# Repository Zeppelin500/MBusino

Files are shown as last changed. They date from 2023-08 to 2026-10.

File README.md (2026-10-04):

# MBusino
<br/>
### M-Bus --> MQTT-Gateway with shields for ESPs

A **Plug and Play** solution.

M-Bus decoding uses the project's own library [**MBusinoLib**](https://github.com/Zeppelin500/MBusinoLib). Test the library [**via Wokwi.**](https://wokwi.com/projects/402235052803622913)
The serial data link layer communication is handled by [**MBusCom**](https://github.com/Zeppelin500/MBusCom).

Mbusino has a captive and setup portal to configure WiFi, MQTT, M-Bus, and Sensors.

## Code

the project is developed with **Arduino IDE 2**, source code and .bin files will be find at the **src** folder.  

**MBusino** code is for a single M-Bus Slave

**MBusino5S** code is for up to 5 Slaves

## Hardware

### MBusino

The original MBusino decodes M-Bus and can also optional read out different sensors, see below. Network connection only via the build in ESP32 WiFi.
- M-Bus e.g. heatmeter (up to five slaves, use the 5S code)
- OneWire 5x DS18B20, temperature
- I²C BME280, temperatur, r. humidity, air pressure

The MBusino is usable for "only M-Bus" or "only sensor measuring" as well. Beside the USB power supply of The ESP is no other adapter necessary.

Use 2,54mm terminals or JST XH to connect the DS18B20

You will find a 3D-printable PCB case inside the case folder. The edition Z need a different case, usable for both versions. 
The PCB is designed with fritzing.

M-Bus is provided by a piggyback M-Bus master.
There are two MBusino versions available for two different M-Bus masters.

The "old" version for a chinese M-Bus Master. 
https://a.aliexpress.com/_EyQhgIZ --> the Master **NOT the Slave!** 
Supported ESP-Boards: ESP8266 D1 mini, or D1 mini Pro(4M) with extern antenna for better Wifi range and the ESP32 S2 mini

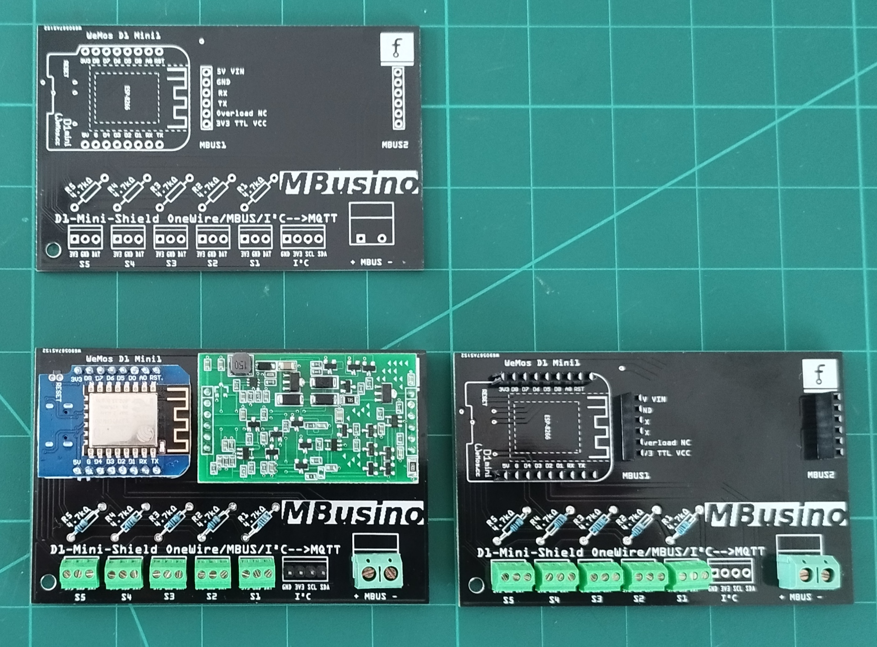
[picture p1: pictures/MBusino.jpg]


The new "**edition Z**" version for a german M-Bus master from Zihatec. Many thanks to HWHardsoft for making the board available especially for us.
https://www.hwhardsoft.de/2024/10/08/m-bus-master-breakout
Work only with the ESP S2 mini.

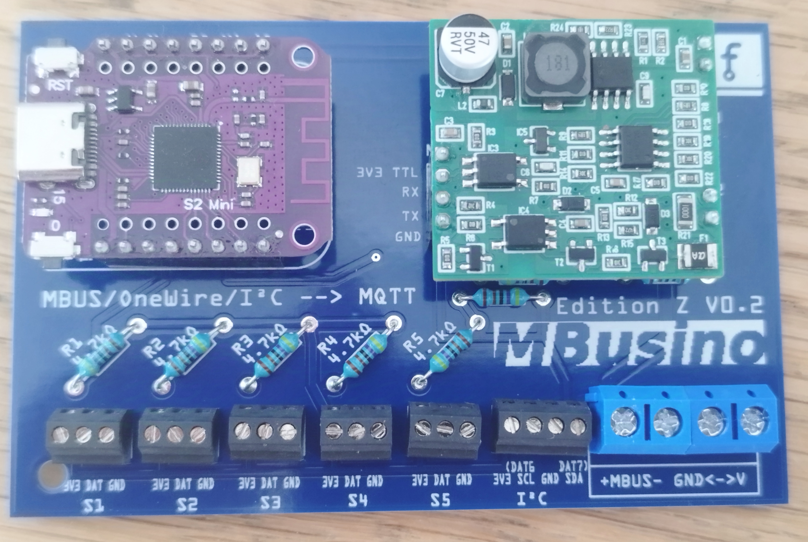
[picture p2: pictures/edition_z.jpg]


### MBusino Nano

A pure M-Bus --> MQTT gateway without extra sensor measuring but with Wifi **and** Ethernet connectivity.
ESP32 C3 Supermini with W5500 Lite Ethernet Modul and Zihatec M-Bus Modul.

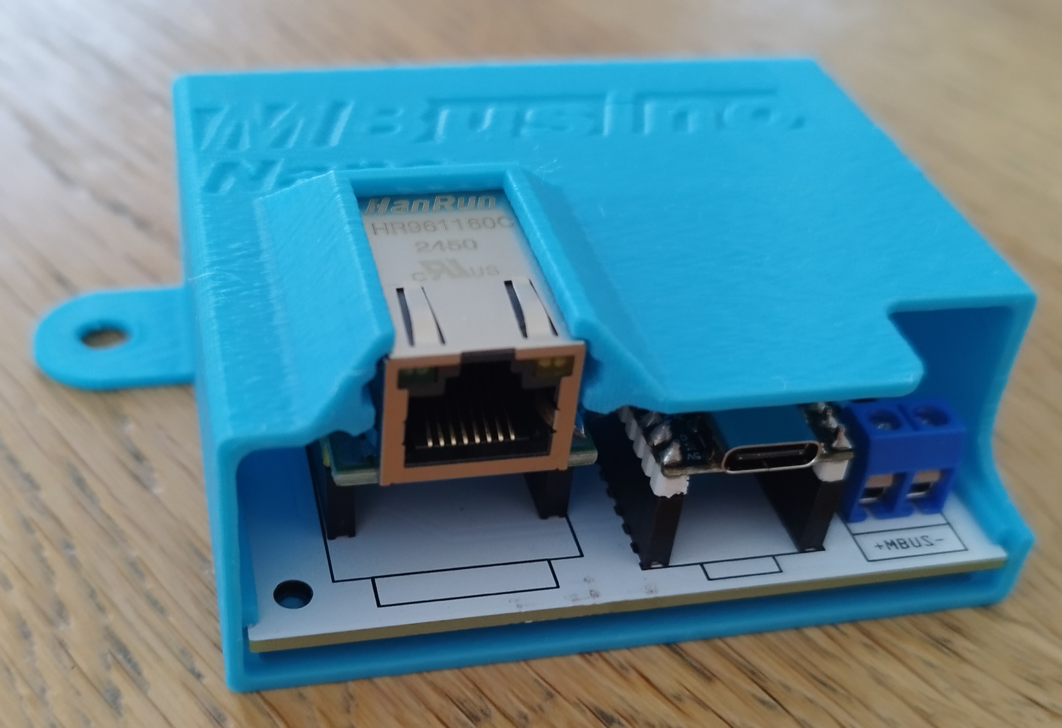
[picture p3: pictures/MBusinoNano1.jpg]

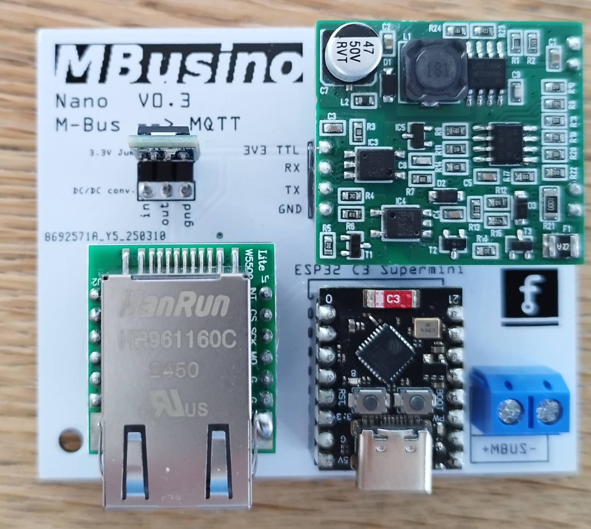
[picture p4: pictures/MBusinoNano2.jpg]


To save money, I place omnibus orders for all parts beside the M-Bus Master.

## Access Point to configure,  MBusino Setup Portal

* SSID **MBusino Setup Portal** IP(normally not needed): 192.168.4.1
* If Mbusino do not find a known network, he start an AP for 5 minutes. After this period, he will restart and search again.
* In known networks, you will find the IP of the portal under **MBusino** in your router.

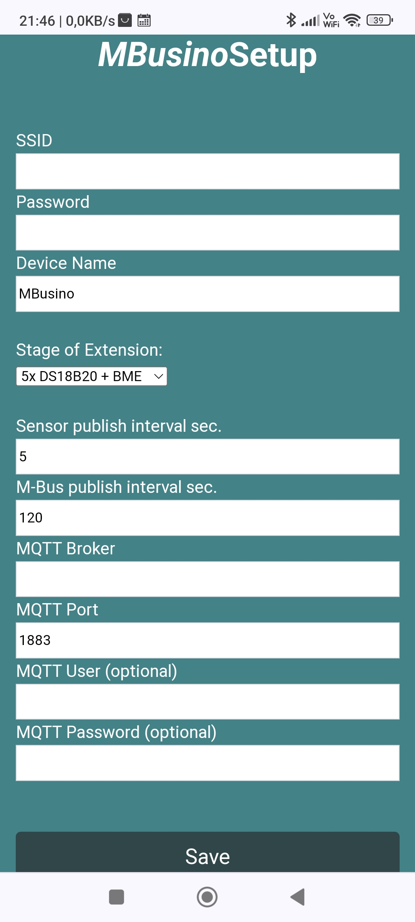
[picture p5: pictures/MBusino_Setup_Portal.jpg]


## MQTT Output
Use MQTT Explorer (PC) or [**MQTT Browser**](https://github.com/ZeppelinsBot/MQTTBrowser) (Android) to see the MQTT Output.

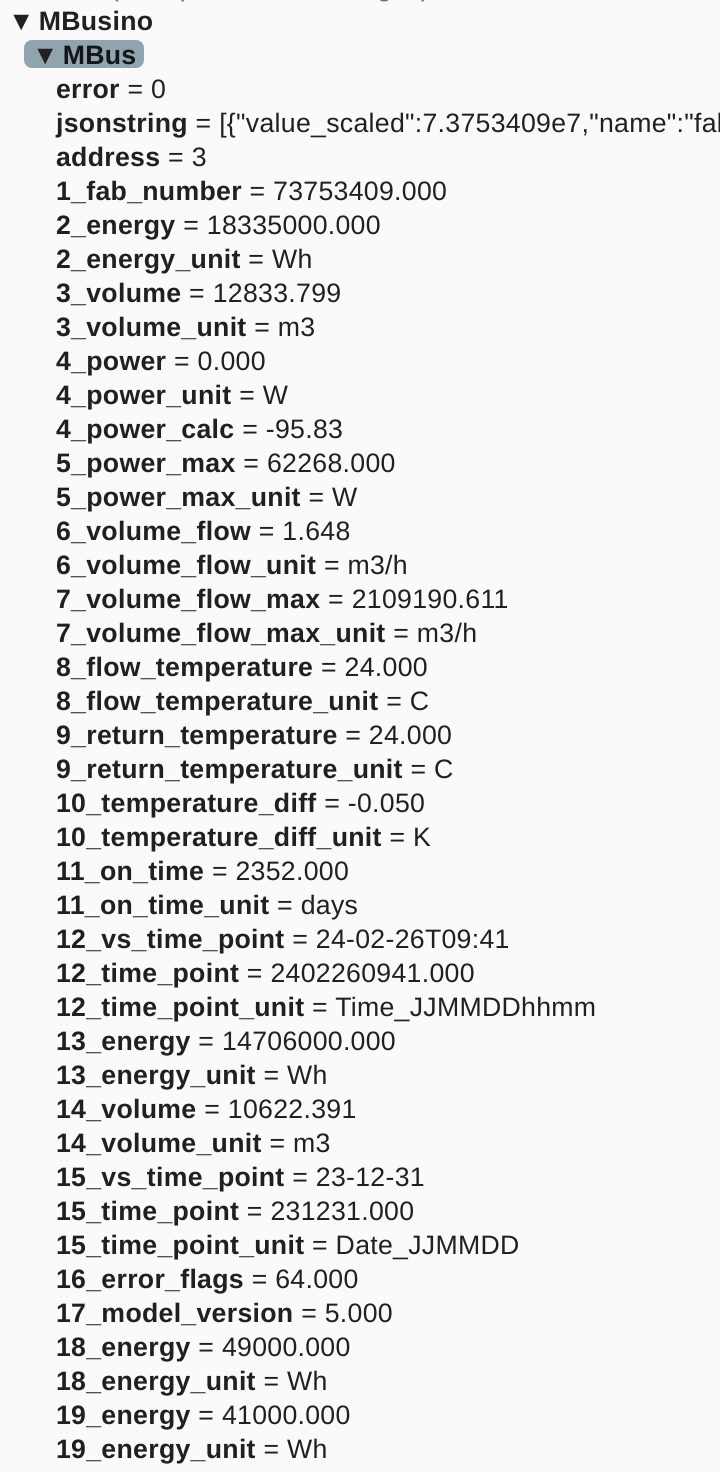
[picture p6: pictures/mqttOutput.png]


## Home-Assistant

If you use Home Assistant, MBusino supports autodiscover. You need only the MQTT integration and MBusino will be find as device with all records.
Every 256th record message is a autodiscover message. 
If you use not Home Assistant, no matter. All records will be send as MQTT message.

## M-Bus Polling (optional)

Normaly M-Bus request is set with an interval at the GUI. But in special cases you can set the interval to a long period to save slave battery life and poll the M-Bus records by a MQTT request as often as you want between. E.g. M-Bus Interval 2.592.000 sec. (30 days) and poll high frequently between in interesting phases.

### MBusino
* MQTT Topic: MBusino/mbusPolling
* MQTT Payload: no matter

### MBusino5S
* MQTT Topic: MBusino/mbusPolling
* MQTT Payload: M-Bus Address in decimal (you can also request addresses witch are not stored in the GUI)

## calibration capabilities 

Most DS18B20 are faked and out of specifications.
You can calibrate the sensors by sending a MQTT message to MBusino.
Subscribe at topic MBusino/cal/# for calibration replies. 

### 1. Set the average of all DS sensors
* MQTT Topic: MBusino/calibrateAverage
* MQTT Payload: no matter

Make the average of the connected sensors and add an offset to every sensor. After the calibration, all sensors will show the same value.
You have to bring all connected sensors to the same environment, wait a little bit and send the calibration message.

### 2. Calibrate to a connected Bosch BME280 Sensor
* MQTT Topic: MBusino/calibrateBME
* MQTT Payload: no matter

Make an offset for every DS sensor based at the meassured value of the BME sensor. After the calibration, all sensors will show the same value.
You have to bring all connected sensors to the same environment, wait a little bit and send the calibration message.

### 3. Calibration by hand
* MQTT Topic: MBusino/calibrateSensor
* MQTT Payload: Number of the Sensor to calibrate (only the number). e.g.S3 = 3
* MQTT Topic: MBusino/calibrateValue
* MQTT Payload: a float number e.g. -0.15

Manipulate the offset of a single sensor by sending sensor numbers and values. The transmitted value will be added to the current offset. First chose the sensor, then send the value. If a sensor is chosed, multiple manipulations of the same sensor are possible.

### 4. Set all offsets to zero
* MQTT Topic: MBusino/calibrateSet0
* MQTT Payload: no matter

Self explanatory.

## known issues / limitations
- Flashing over USB is only possible, if the M-Bus master is not connected (only D1 mini). OTA update work fine.

- Do not use 2 Boards simultaneously without changing thr Name or it cause in network problems, both boards becomes unreachable. 

- M-Bus should work with most M-Bus devices. If you have M-Bus issues, let me know.

- ~~No support of multi telegram messages. Only the first telegram will be decoded~~ done!

- ~~passwords are limited to 29 characters~~ done! now 64 characters 

- If no broker is connected. M-Bus communication is disabled. So, you can't also not change M-Bus addresses from the access point connection.
  
- Some power delivery / quick charge power supplies switch off afer a certain time, because the MBusino requires too little power. Use old addapters without "intelligence". 1A is more then enough.

## Credits
* AllWize for the MbusPayload library -- the first code base of the MBusinoLib to decode M-Bus
* HWHardsoft and TrystanLea for the M-Bus communication

## Current topics

https://github.com/Zeppelin500/MBusino/discussions

## Tutorial

https://github.com/Zeppelin500/MBusino/tree/main/tutorial

## Licence
****************************************************
This program is free software: you can redistribute it and/or modify it under the terms of the GNU General Public License as published by
the Free Software Foundation, either version 3 of the License, or (at your option) any later version. This program is distributed in the hope that it will be useful,
but WITHOUT ANY WARRANTY; without even the implied warranty of MERCHANTABILITY or FITNESS FOR A PARTICULAR PURPOSE.  See the GNU General Public License for more details.
You should have received a copy of the GNU General Public License along with this program.  If not, see <http://www.gnu.org/licenses/>.
****************************************************
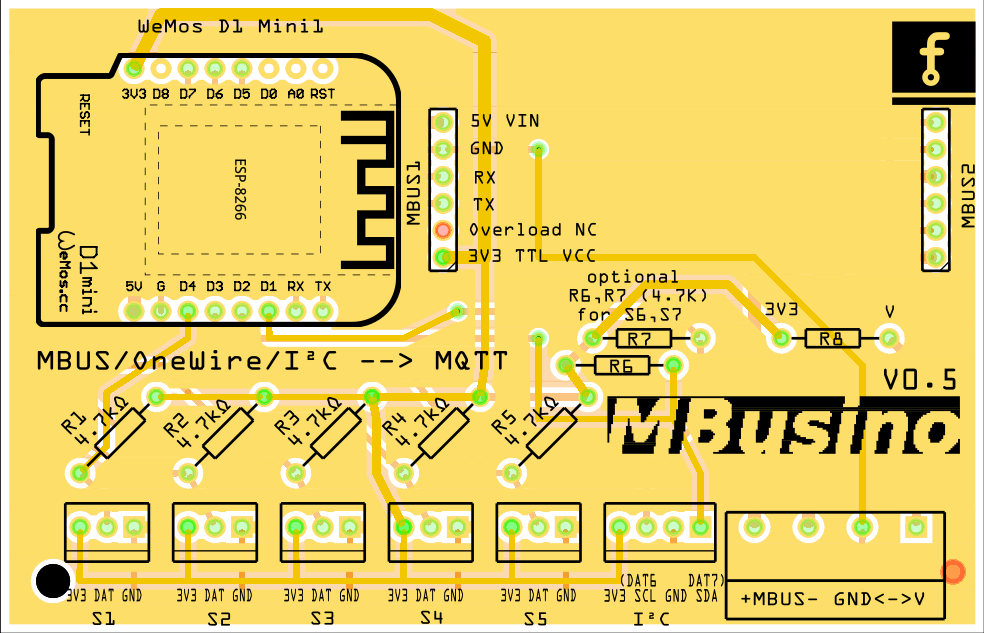
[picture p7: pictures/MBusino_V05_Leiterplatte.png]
PCB

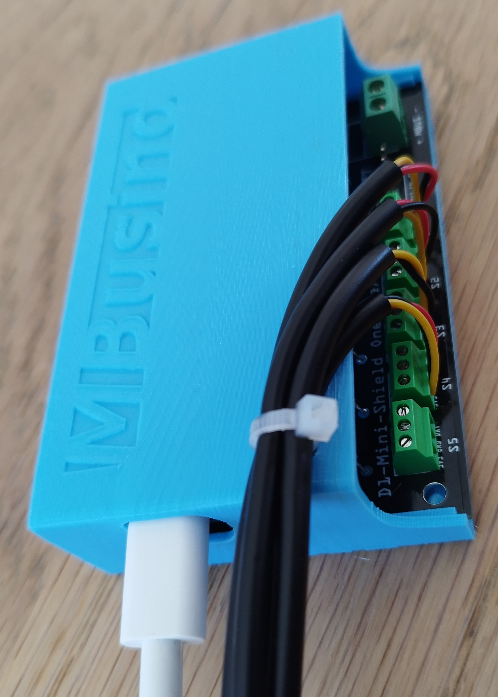
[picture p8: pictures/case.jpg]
Bild


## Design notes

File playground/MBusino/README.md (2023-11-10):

# MBusino
ESP8266 D1 Mini Shield for meassuring and sending some values with MQTT

- M-Bus e.g. heatmeter 
- OneWire 5x z.B. DS18B20, temperature
- I²C z.B. BME280, temperatur, r. humidity, air pressure

* the "old Sensostar only" code is archived.

## Hardware
The PCB is designed with fritzing.
M-Bus is provided by a piggyback M-Bus master.
https://de.aliexpress.com/item/33008746192.html --> the Master!

Beside the USB power supply of D1 Mini is no other adapter necessary.

The Board is usable for only M-Bus (see MBusino_naked code) or only sensor meassuring as well.  

you can use 2,54mm terminals or JST XH to connect the DS18B20

You will find a 3D-printable PCB case inside the case folder.  

To save mony, I place omnibus orders for all parts.

## calibration capabilitys. 

Most DS18B20 are faked and out of specifications.
You can calibrate the sensors by sending a MQTT message to MBusino.

### 1. Set the average of all DS sensors
* MQTT Topic: CMBusino/calibrateAverage
* MQTT Payload: no matter

Make the average of the connected sensors and add an offset to every sensor. After the calibration, all sensors will show the same value.
You have to bring all connected sensors to the same environment, wait a little bit and send the calibration message.

### 2. Calibrate to a connected Bosch BME280 Sensor
* MQTT Topic: CMBusino/calibrateBME
* MQTT Payload: no matter

Make an offset for every DS sensor based at the meassured value of the BME sensor. After the calibration, all sensors will show the same value.
You have to bring all connected sensors to the same environment, wait a little bit and send the calibration message.

### 3. Calibration by hand
* MQTT Topic: CMBusino/calibrateSensor
* MQTT Payload: Number of the Sensor to calibrate (only the number). e.g.S3 = 3
* MQTT Topic: CMBusino/calibrateValue
* MQTT Payload: a float number e.g. -0.15

Manipulate the offset of a single sensor by sending Sensor numbers and values. The transmitted value will be added to the current offset. First chose the sensor, then send the value. If a sensor is chosed, you can manipulate multiple times the same sensor.

### 4. Set all offsets to 0
* MQTT Topic: CMBusino/calibrateSet0
* MQTT Payload: no matter

Self explanatory.

## known issues
- Flashing over USB is only possible if the M-Bus master is not connected. OTA update work fine.

- Do not use 2 Boards without changing the name. #define MBUSINO_NAME "MBusino"

- M-Bus is only tested with a "Engelmann Sensostar U" at the moment, but should work with other M-Bus divices. If you have M-Bus issues, let me know.

- Code will only work with the modified MBUSPayload library. 

https://github.com/Zeppelin500/mbus-payload

## Credits
* AllWize for the library to decode M-Bus
* HWHardsoft for the M-Bus communication

## current topics

https://github.com/Zeppelin500/MBusino/discussions

## Lizenz
****************************************************
This program is free software: you can redistribute it and/or modify it under the terms of the GNU General Public License as published by
the Free Software Foundation, either version 3 of the License, or (at your option) any later version. This program is distributed in the hope that it will be useful,
but WITHOUT ANY WARRANTY; without even the implied warranty of MERCHANTABILITY or FITNESS FOR A PARTICULAR PURPOSE.  See the GNU General Public License for more details.
You should have received a copy of the GNU General Public License along with this program.  If not, see <http://www.gnu.org/licenses/>.
****************************************************
PCB
Bild
Bild

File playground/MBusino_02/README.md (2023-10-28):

# MBusino
Ein ESP8266 D1 Mini Shield zur Aufnahme verschiedener Messwerte und deren Versand per MQTT

* Code funktioniert nur mit der veränderten MBUSPayload Libary. 

* Jetzt sollten verschiedene M-Bus Slaves ausgelesen werden können. 

https://github.com/Zeppelin500/mbus-payload

## Danke  

* an AllWize für die Libary zum dekodieren und
* an HWHardsoft für die M-Bus Kommunikation

## Lizenz GPL3
****************************************************
This program is free software: you can redistribute it and/or modify it under the terms of the GNU General Public License as published by
the Free Software Foundation, either version 3 of the License, or (at your option) any later version. This program is distributed in the hope that it will be useful,
but WITHOUT ANY WARRANTY; without even the implied warranty of MERCHANTABILITY or FITNESS FOR A PARTICULAR PURPOSE.  See the GNU General Public License for more details.
You should have received a copy of the GNU General Public License along with this program.  If not, see <http://www.gnu.org/licenses/>.
****************************************************

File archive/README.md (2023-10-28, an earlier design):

# MBusino
Ein ESP8266 D1 Mini Shield zur Aufnahme verschiedener Messwerte und deren Versand per MQTT

- M-Bus z.B. Wärmemengenzähler 
- OneWire 5x z.B. DS18B20, Temperatur
- I²C z.B. BME280, Temperatur, rel. Luftfeuchte, Luftdruck

## Hardware
Das Shield ist ein mit Fritzing konstruiertes Board.
Der M-Bus wird über einen aufsteckbaren M-Bus Master bereitgestellt.
https://de.aliexpress.com/item/33008746192.html --> der Master!

Ausser der USB Spannungsversorgung des D1 Mini ist kein weiteres Netzteil nötig.

## known issues
- Flashen über USB ist nur möglich, wenn der MBus Master nicht aufgesteckt ist. OTA Update geht aber.

- Das Projekt befindet sich im Aufbau. Der Code ist funktionsfähig. M-BUS ist bis jetzt nur mit dem Sensostar U implementiert.

- ~~Beim aktuellen Prototypen ist die Beschriftung von 3V3 und DAT bei den OneWire Sensoren vertauscht (S1-S5).~~ [bei V0.3 behoben]

## Danke
Der M-Bus Teil und die Headerdateien sind ein Extrakt aus https://github.com/NerdyProjects/HousebusNode_Heatpump
Danke an User NerdyProjects 

## Aktuelles
Hier oben unter Discussion sind die aktuellen Entwicklungsideen zu finden. Beteiligung ist gerne gesehen.
https://github.com/Zeppelin500/MBusino/discussions

* neueste Entwicklung: **MBusino_naked** https://github.com/Zeppelin500/MBusino/tree/main/SRC/MBusino_naked

## Lizenz
****************************************************
This program is free software: you can redistribute it and/or modify it under the terms of the GNU General Public License as published by
the Free Software Foundation, either version 3 of the License, or (at your option) any later version. This program is distributed in the hope that it will be useful,
but WITHOUT ANY WARRANTY; without even the implied warranty of MERCHANTABILITY or FITNESS FOR A PARTICULAR PURPOSE.  See the GNU General Public License for more details.
You should have received a copy of the GNU General Public License along with this program.  If not, see <http://www.gnu.org/licenses/>.
****************************************************
PCB
Bild
Bild

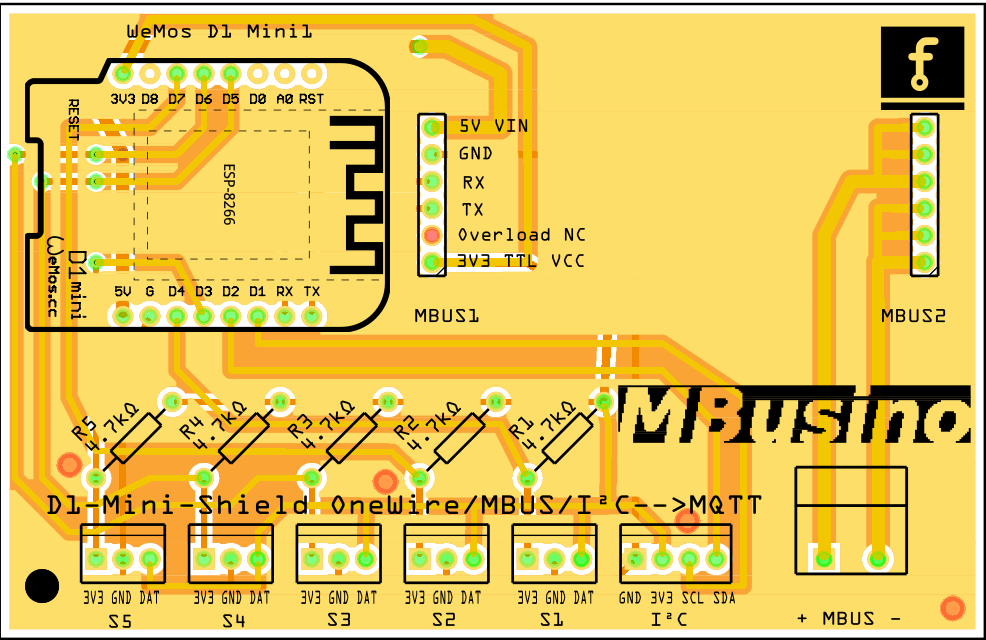
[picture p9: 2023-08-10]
pictures/MBusino.png

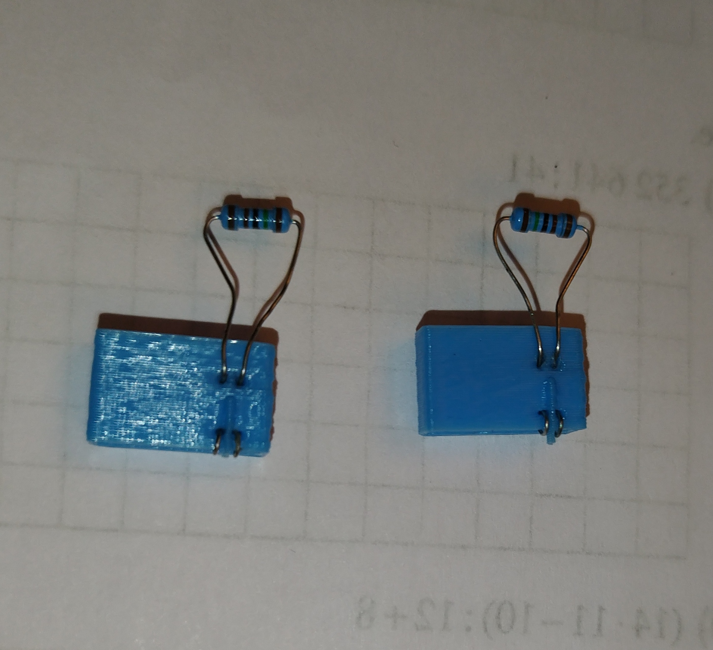
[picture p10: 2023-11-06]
sensostar_dongle/picture3.jpg

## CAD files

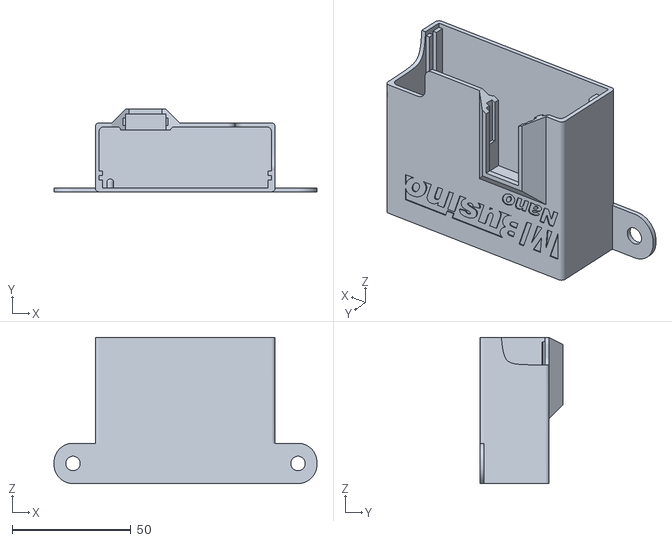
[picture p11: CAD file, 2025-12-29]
case/MbusinoNano v13.stl
110.8 x 34.8 x 61.6

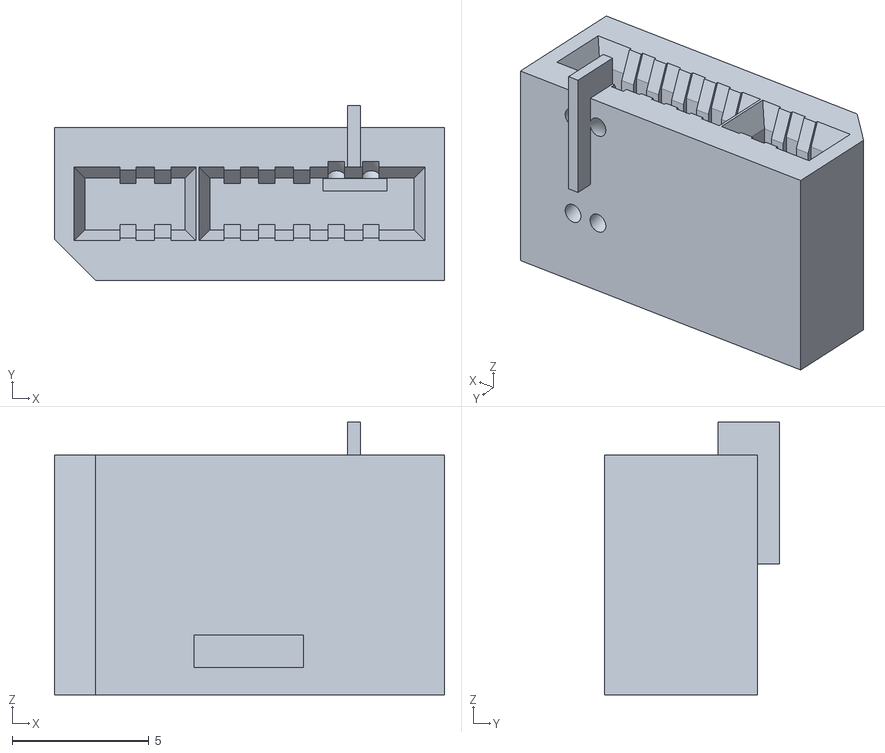
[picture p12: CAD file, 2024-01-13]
sensostar_dongle/stecker v18.stl
14.3 x 6.40 x 9.98

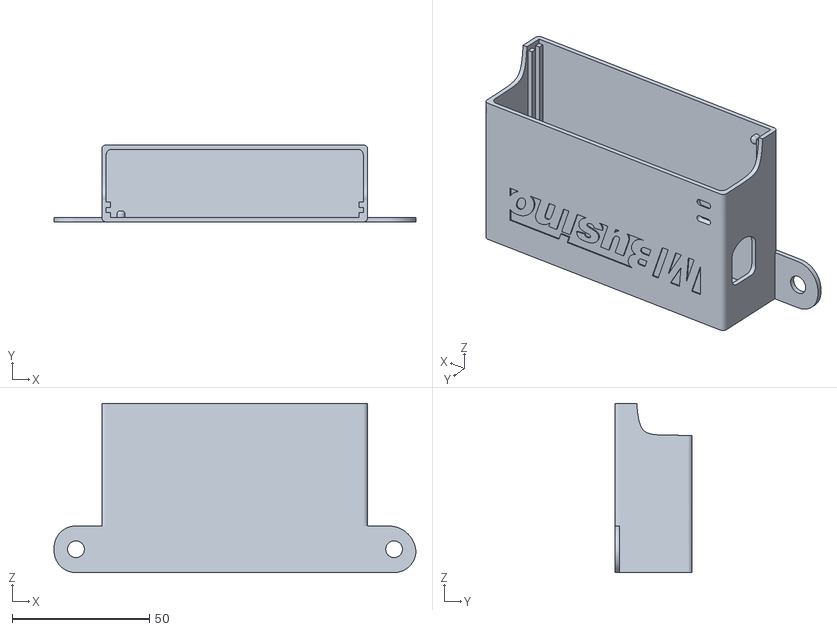
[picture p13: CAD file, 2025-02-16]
case/MbusinoZ v7.stl
131.8 x 28.1 x 61.6

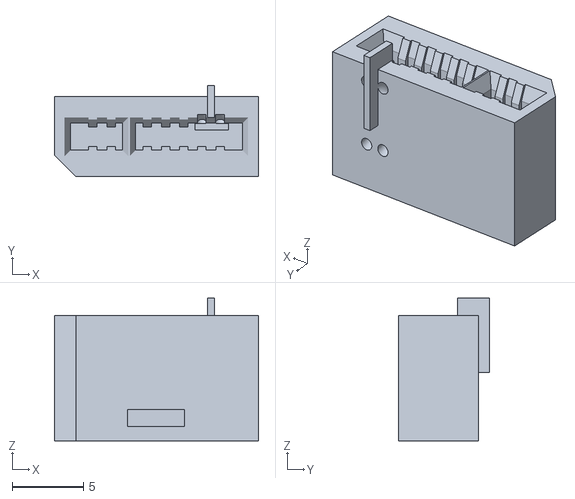
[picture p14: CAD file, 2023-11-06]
sensostar_dongle/sensostar_dongle.stl
14.3 x 6.40 x 9.98

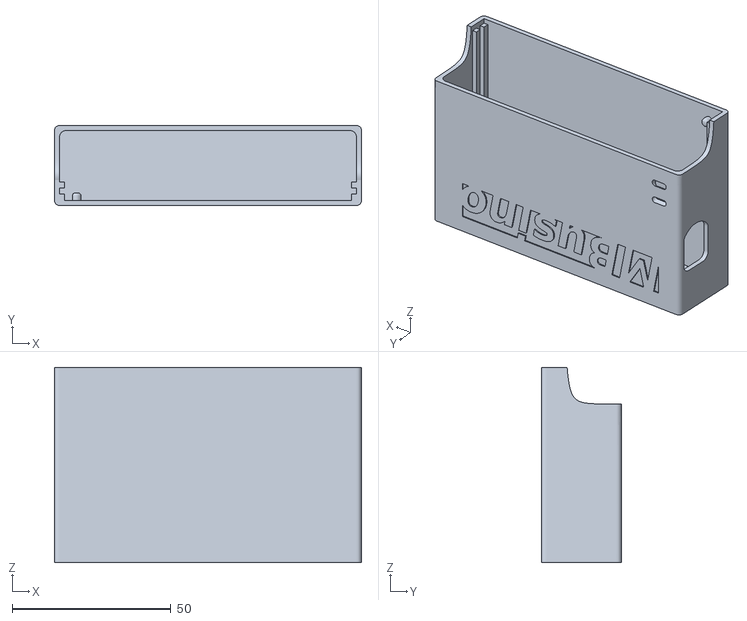
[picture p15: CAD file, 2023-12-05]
case/Mbusino v05.stl
96.8 x 25.2 x 61.6

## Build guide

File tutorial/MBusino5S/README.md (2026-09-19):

# MBusino5S Tutorial

MBusino5S work on **ESP8266 D1 Mini** or **ESP32 S2 Mini**. For both boards are .bin files provided.

https://github.com/Zeppelin500/MBusino/blob/main/src/MBusino5S/build

The Pinout configuration of the ESP32 S2 mini is exactly the same like D1 mini. Equip only the two outside pin headers. 

**Do all steps of the MBusino tutorial (with the MBusino 5S files) and additional the following steps.**
**!Flashing of ESP32 S2 mini is different to the ESP8266 D1 mini, use this [tutorial](https://github.com/Zeppelin500/MBusino/blob/main/tutorial/Flashing_ESP32S2_Mini/README.md)**

## configure MBusino5S

* Number of connected M-Bus Slaves. The Master can handle a maximum of 5 Slaves.
* If you use only 1 slave, set Address 1 to 254. 254 stands for Broadcast and the real address of the slave does no matter.
* If you use more then one slave, you have to set the primary address of the slaves. Possible addresses are 0-250. The connected slaves addresses has to be different! 
* Note, that the M-Bus interval is the time between the M-Bus requests. So if you use 3 slaves and set the interval to 10 seconds. Every single master will answer in a 30 second interval. Minimum is 4 or 5 seconds before the bus were stumbling.
* In delivery condition, the address is 0.

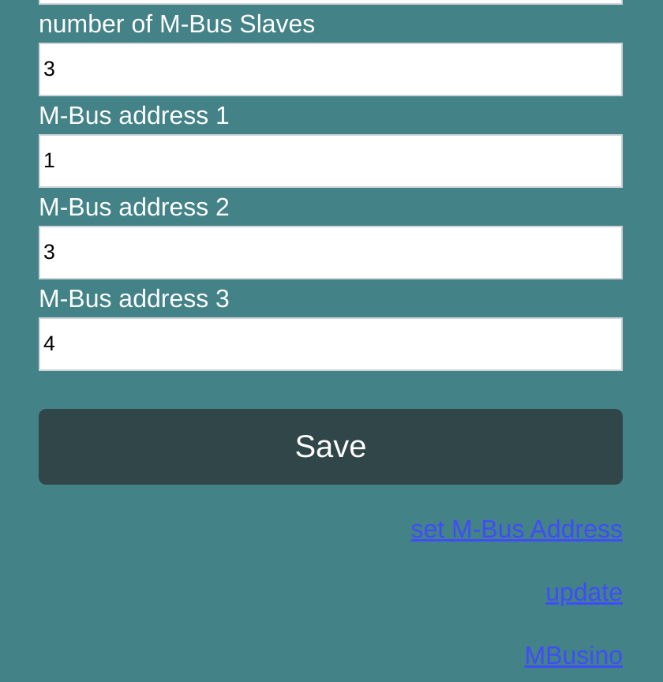
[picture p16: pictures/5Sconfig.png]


## Change the primary addresses of your slaves

* go to **[MBusino_IP]/setaddress**
* only one slave can be connected during setting addresses!
* Choose an address at the drop down and save. 
* the slave should now have the new address 

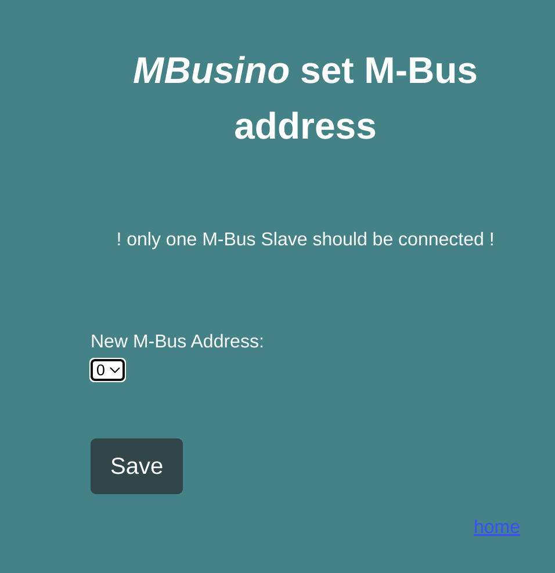
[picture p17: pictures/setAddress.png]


## Output

The MQTT topic output of the MBusino5S is different to the MBusino!
MBus Address is now part of the MQTT topic. So you have to change your Home Assistant config.

MBusino MBus topic:
**MBusino/MBus/6_volume_flow**

MBusino5S MBus topic:
**MBusino/MBus/SlaveAddress3/6_volume_flow**

### Autodiscover

from version 0.9.1, MBusino5S supports Home Assistant autodiscover. You need only the MQTT integration and MBusino will be find as device with all records.
The third record message is a autodiscover message and every 256th recurring.

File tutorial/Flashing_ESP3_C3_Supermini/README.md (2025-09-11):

# Flashing ESP32 C3 supermini for MBusino Nano

For the ESP32 C3 are 3 different .bin files created.

**MBusinoNano**

* MBusinoNano.ino.bootloader.bin
* MBusinoNano.ino.partitions.bin
* MBusinoNano.ino.bin 

https://github.com/Zeppelin500/MBusino/tree/main/src/MBusinoNano/build/esp32.esp32.makergo_c3_supermini

**MBusinoNano5S**

* MBusinoNano5S.ino.bootloader.bin
* MBusinoNano5S.ino.partitions.bin
* MBusinoNano5S.ino.bin 

https://github.com/Zeppelin500/MBusino/tree/main/src/MBusinoNano5S/build/esp32.esp32.makergo_c3_supermini

### Use for Flashing https://adafruit.github.io/Adafruit_WebSerial_ESPTool/

* connect the S2 Mini with USB
* press and hold the boot button, press the reset button, release the boot botton. 
* press **Connect** and choose the USP Port
* if connected click **Erase** and wait for finish
* may you have to connect again
* if connected, load all 3 .bin files as follows with the offset

**MBusino**

* Offset 0x 0000    MBusinoNano.ino.bootloader.bin
* Offset 0x 8000    MBusinoNano.ino.partitions.bin
* Offset 0x 10000    MBusinoNano.ino.bin 

**MBusinoNano5S**

* Offset 0x 0000    MBusinoNano5S.ino.bootloader.bin
* Offset 0x 8000    MBusinNano5S.ino.partitions.bin
* Offset 0x 10000    MBusinoNano5S.ino.bin 

--> done

**The offset of the bootloader in the screenshots are wrong. Use The values above.** 

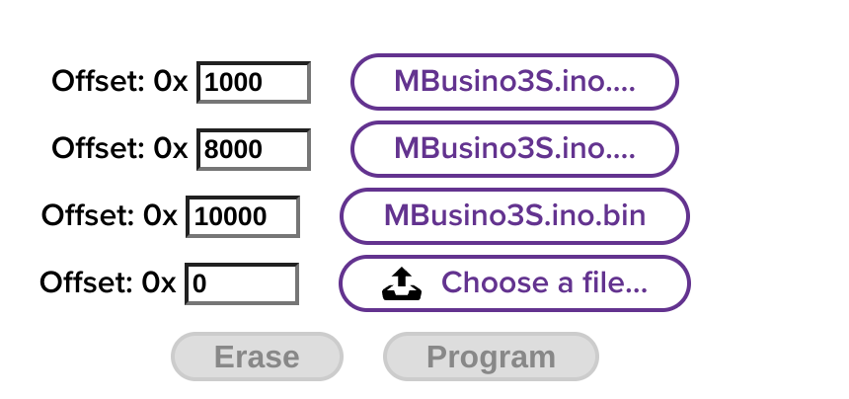
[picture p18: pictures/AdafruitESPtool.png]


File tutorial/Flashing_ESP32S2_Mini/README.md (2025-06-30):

# Flashing ESP32 S2 Mini

For the ESP32 S2 are 3 different .bin files created.

**MBusino**

* MBusino.ino.bootloader.bin
* MBusino.ino.partitions.bin
* MBusino.ino.bin 

https://github.com/Zeppelin500/MBusino/tree/main/src/MBusino/build/esp32.esp32.lolin_s2_mini

**MBusino5S**

* MBusino5S.ino.bootloader.bin
* MBusino5S.ino.partitions.bin
* MBusino5S.ino.bin 

https://github.com/Zeppelin500/MBusino/tree/main/src/MBusino5S/build/esp32.esp32.lolin_s2_mini

### Use for Flashing https://adafruit.github.io/Adafruit_WebSerial_ESPTool/

* connect the S2 Mini with USB
* press and hold the boot button, press the reset button, release the boot botton. 
* press **Connect** and choose the USP Port
* if connected click **Erase** and wait for finish
* may you have to connect again
* if connected, load all 3 .bin files as follows with the offset

**MBusino**

* Offset 0x 1000    MBusino.ino.bootloader.bin
* Offset 0x 8000    MBusino.ino.partitions.bin
* Offset 0x 10000    MBusino.ino.bin 

**MBusino5S**

* Offset 0x 1000    MBusino5S.ino.bootloader.bin
* Offset 0x 8000    MBusino5S.ino.partitions.bin
* Offset 0x 10000    MBusino5S.ino.bin 

--> done



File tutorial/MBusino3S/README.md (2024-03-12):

# MBusino3S Tutorial, 3S for three Slaves

MBusino3S work on **ESP8266 D1 Mini** or **ESP32 S2 Mini**. For both boards are .bin files provided.

https://github.com/Zeppelin500/MBusino/blob/main/src/MBusino3S/build

The Pinout configuration of the ESP32 S2 mini is exactly the same like D1 mini. Equip only the two outside pin headers. 

**Do all steps of the MBusino tutorial (with the MBusino 3S files) and additional the following steps.**
**!Flashing of ESP32 S2 mini is different to the ESP8266 D1 mini, use this [tutorial](https://github.com/Zeppelin500/MBusino/blob/main/tutorial/Flashing_ESP32S2_Mini/README.md)**

## configure MBusino3S

* Number of connected M-Bus Slaves. The Master can handle a maximum of 3 Slaves.
* If you use only 1 slave, set Address 1 to 254. 254 stands for Broadcast and the real address of the slave does no matter.
* If you use more then one slave, you have to set the primary address of the slaves. Possible addresses are 0-250. The connected slaves addresses has to be different! 
* Note, that the M-Bus interval is the time between the M-Bus requests. So if you use 3 slaves and set the interval to 10 seconds. Every single master will answer in a 30 second interval. Minimum is 4 or 5 seconds before the bus were stumbling.
* In delivery condition, the address is 0.



## Change the primary addresses of your slaves

* go to **[MBusino_IP]/setaddress**
* only one slave can be connected during setting addresses!
* Choose an address at the drop down and save. 
* the slave should now have the new address 



## Output

The MQTT topic output of the MBusino3S is different to the MBusino!
MBus Address is now part of the MQTT topic. So you have to change your Home Assistant config.

MBusino MBus topic:
**MBusino/MBus/6_volume_flow**

MBusino3S MBus topic::
**MBusino/MBus/SlaveAddress3/6_volume_flow**

### Autodiscover

from version 0.9.1, MBusino3S supports Home Assistant autodiscover. You need only the MQTT integration and MBusino will be find as device with all records.
The third record message is a autodiscover message and every 256th recurring.

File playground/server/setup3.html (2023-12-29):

# MBusinoSetup

SSID

Password

Device Name

Stage of Extension:

Sensor publish interval sec.

M-Bus publish interval sec.

MQTT Broker

MQTT Port

MQTT User (optional)

MQTT Password (optional)

Save

MBusino (https://www.github.com/zeppelin500/mbusino)

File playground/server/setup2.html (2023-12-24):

# MBusino Setup

SSID

Password

Device Name

Stage of Extension:

MQTT Broker

MQTT Port

MQTT User (optional)

MQTT Password (optional)

Save

MBusino (https://www.github.com/zeppelin500/mbusino)

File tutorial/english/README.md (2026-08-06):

# MBusino Tutorial English

**Edition Z for the Zihatec M-Bus Master is using a ESP32 S2 mini! Skip flashing of ESP 8266 D1 mini and use this [tutorial](https://github.com/Zeppelin500/MBusino/blob/main/tutorial/Flashing_ESP32S2_Mini/README.md) for flashing. **For MBusino Nano use this [flash tutorial](https://github.com/Zeppelin500/MBusino/blob/main/tutorial/Flashing_ESP3_C3_Supermini/README.md).** Start then with Point 9**

## You can flash the MBusino with https://web.esphome.io

1. Download the Bin from https://github.com/Zeppelin500/MBusino/blob/main/src/MBusino/build/esp8266.esp8266.d1_mini/MBusino.ino.bin

2. open https://web.esphome.io with the Chrome-Browser

3. Connect your 8266er with the COM-Port XX

4. Click on "INSTALL" not "PREPARE FOR FIRST USER
Step4

5. Click on "Datei auswählen" and chose MBusino.ino.bin
Step5

6. Click on "INSTALL"
Step6

7. Wait for finishing the Flash-Process
Step7

8. Flashing is completed successfully 
Step8

9. Search the MBusino Wlan Access-Point "MBusino Setup Portal" with your Smartphone

10. Configure your Mqtt-Broker and your WLAN

SetupPortal

* With multible MBusino in network, you have to change the name or it caouse in network problems .
* Minimum for intervalls is Sensors 2 sec., M-Bus 4 sec. 
* At MQTT Broker you can set an IP or a address. E.g. **192.168.1.7** oder **test.mosquitto.org** no https:// oder mqtt:// only addresse

If MBusino do not find a known network, Accesspoint will accessable for 5 minutes. after this periode he restart and search again.
You will find the IP in your router.

## MQTT and HomeAssistant

### Autodiscover

from version 0.9.0, MBusino supports Home Assistant autodiscover. You need only the MQTT integration and MBusino will be find as device with all records.
The third record message is a autodiscover message and every 256th recurring.

### per hand

With the Software **MQTT Explorer** at PC or [**MQTT Browser**](https://github.com/ZeppelinsBot/MQTTBrowser) at your mobile you will see the mqtt messages.
in attachement you will find a HA Config file as example. But you have to change something to your MQTT messages.

Every value has its own sensor. **state_topic** is the MQTT topic, depends on the topics at MQTT Explorer.
```
mqtt:
 sensor:
     - unique_id: MBusino_Leistung
      name: "Leistung"
      device_class: power
      state_topic: "MBusino/MBus/4_power"     
      unit_of_measurement: "W"
```

## MBusino update

With the ESPHome Webtool, you will loose al your datas during update. Use instead  **[IP_of_MBusino]/update** and all datas will retain.

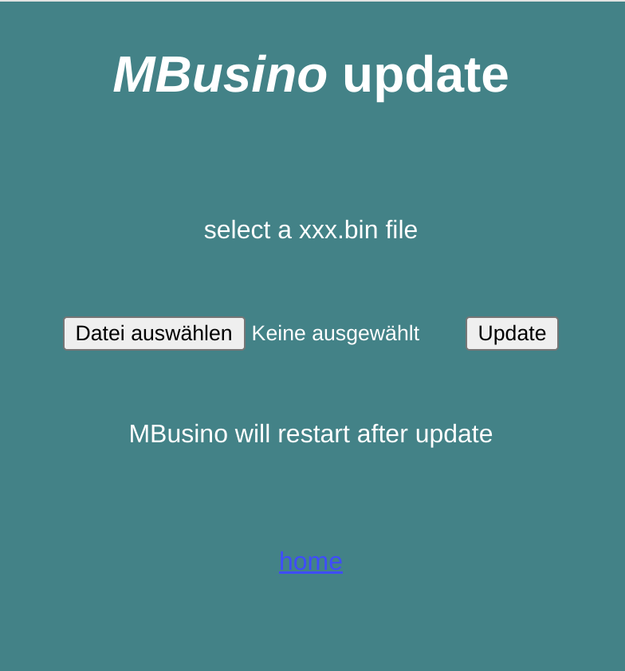
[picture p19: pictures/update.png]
Update


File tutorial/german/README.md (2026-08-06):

# MBusino Tutorial deutsch

**Bei der Edition Z für den Zihatec M-Bus Master ist ein ESP32 S2 mini verbaut! Daher die unten stehenden Anweisungen zum flashen des ESP8266 D1 mini überspringen und diese [Anweisung](https://github.com/Zeppelin500/MBusino/blob/main/tutorial/Flashing_ESP32S2_Mini/README.md) anstatt dessen nutzen.**
**Für den MBusino Nano diese [flash Anleitung](https://github.com/Zeppelin500/MBusino/blob/main/tutorial/Flashing_ESP3_C3_Supermini/README.md) nutzen.**
**Dann bei Punkt 9 weiter machen.**

## für das flashen des MBusino ist keine Software nötig. Wir nutzen https://web.esphome.io

1. Downloaden des .bin Files von https://github.com/Zeppelin500/MBusino/blob/main/src/MBusino/build/esp8266.esp8266.d1_mini/MBusino.ino.bin

2. öffne https://web.esphome.io mit z.B. dem Chrome-Browser (geht nicht am Handy)

3. Verbinde den ESP8266 D1 mini per USB

4. Click auf **INSTALL** nicht "PREPARE FOR FIRST USER
Step4

5. Click auf "Datei auswählen" and chose MBusino.ino.bin
Step5

6. Click auf "INSTALL"
Step6

7. Warte bis der Flash-Prozess beendet ist
Step7

8. Flashing is completed successfully 
Step8

9. Suche und verbinde dich mit dem MBusino Wlan Access-Point **MBusino Setup Portal** mit z.B. dem Handy

10. Gib deine Daten ein und speichere.

SetupPortal

* Bei mehreren MBusino im Netz ist der Name zu ändern, sonst kommt es zu Netzwerkproblemen.
* Das Minimum bei den Intervallen dürte bei den Sensoren bei 2 Sec. liegen, bei M-Bus 4 sec. 
* Bei MQTT Broker kann eine IP oder eine Adresse eingegeben weren. z.B. **192.168.1.7** oder **test.mosquitto.org** kein https:// oder mqtt:// nur die Adresse

Wenn der MbusinoAP beim hochfahren kein bekanntes Netzwerk findet, stellt er für 5 Minuten den AP bereit, danach resettet er selbstständig und sucht erneut ein bekanntes Netzwerk.
Im Wlan findet ihr das Portal dauerhaft. IP müsst ihr in der Fritzbox o.ä. suchen.

Falls ihr den Mbusino nicht im eigenen Netzwerk findet, sind die WLAN Zugangsdaten falsch eingegeben. Dann sucht wieder nach dem Acesspoint.

## MQTT und HomeAssistant

### Autodiscover

Von Version 0.9.0 an unterstützt MBusino Home Assistant Autodiscover. Ihr braucht nur die MQTT Integration. Dann wird MBusino automatisch mit allen Werten als Gerät gefunden.
Die dritte MQTT-Nachricht ist eine Autodiscover Nachricht. Danach jede 256te.

### per Hand

Über die Software **MQTT Explorer** am PC oder [**MQTT Browser**](https://github.com/ZeppelinsBot/MQTTBrowser) auf Android könnt ihr jetzt sehen was gesendet wird. Ich empfehehle den MQTT Explorer.
Je nach M-Bus Gerät sehen die Nachrichten unterschiedlich aus. Im Anhang findet ihr eine Beispielauszug der Config für HomeAssistant mit einem Sensostar U.
Je nach dem was ihr empfangt, muss die Datei angepasst werden.

Die Logik ist folgende, für jeden Wert einen Sensor. **state_topic** ist das MQTT topic, das ihr im MQTT Explorer findet.
```
mqtt:
 sensor:
     - unique_id: MBusino_Leistung
      name: "Leistung"
      device_class: power
      state_topic: "MBusino/MBus/4_power"     
      unit_of_measurement: "W"
```

## MBusino updaten

Über das ESPHome Webtool werden alle eingegebenen Daten gelöscht. Wenn ihr den MBusino auf eine neuere oder ander Version updaten wollt, gebt ihr im Browser **[IP_des_MBusino]/update** ein und flasht darüber das neue .bin File. Alle Daten bleiben erhalten.

Update

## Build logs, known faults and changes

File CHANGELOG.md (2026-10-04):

# MBusino change log

The format is based on [Keep a Changelog](http://keepachangelog.com/)
and this project adheres to [Semantic Versioning](http://semver.org/).

## [1.1.2] - 2026-10-04

### Fixed

- **HA `expire_after` for M-Bus sensors now accounts for the slave rotation (MBusino5S, MBusinoNano5S):** it was previously `3 × mbusInterval` regardless of `mbusSlaves`, but each slave is only polled once per full rotation (`mbusSlaves × mbusInterval`). With 3 or more configured slaves the sensors could expire in Home Assistant between two of their updates and show "unavailable" depending on the polling phase (issue #65). Now `expire_after = 3 × mbusSlaves × mbusInterval`, preserving the "3 missed updates" rule per slave. Single-slave variants (MBusino, MBusinoNano) were already correct.

## [1.1.1] - 2026-08-02

### Fixed
- Guard `_vs_` and `_unit` MQTT publishes against NULL/empty values. Empty topics were published for records without ASCII values or units. Now only publishes when value actually exists.

## [1.1.0] - 2026-07-15

### ⚠️ Breaking Change

- **LWT topic changed:** The MQTT Last Will and Testament now uses `{name}/status` with payload `"offline"`, QoS 1, retained. Previously the LWT was published to the bare device name topic with payload `"I am going offline"`, QoS 0, not retained. If you subscribed to the old LWT topic, update your subscription to `{name}/status`.

### Added

- HA availability for all entities: every discovery payload now includes `availability_topic`, `payload_available`, `payload_not_available`. MBusino going offline → all HA entities immediately show unavailable.
- `expire_after` for M-Bus sensors (3× polling interval). If a single M-Bus slave stops responding while MBusino stays connected, only that slave's sensors become unavailable.
- `expire_after` for OneWire/BME280 sensors (3× sensor interval).
- Retained `"online"` status published on `{name}/status` after each MQTT connect.

### Fixed

- **LWT sprintf bug:** `mbusinoName` was used as format string, `/lastwill` suffix silently dropped. Fixed with `snprintf`.
- **value_template fallback removed:** Replaced `{{value_json if value_json is defined else 0}}` with `{{value_json}}`. Broken payloads now keep previous HA state instead of reporting 0.
- Autodiscover buffer increased from 500 to 1024 bytes.

### Dependencies

- MBusinoLib 0.9.20
- MBusCom 0.1.9
- ArduinoJson 7.4.3
- ESP Async WebServer 3.10.3 (ESP32Async)
- Async TCP 3.4.10 (ESP32Async)

## [1.0.4] - 2026-07-10

### Fixed

- Reverted buffer define to MBUS_DATA_SIZE for MBusCom v0.1.9 compatibility
- Depends on MBusCom 0.1.9 (fixed get_response timeout bug)

## [1.0.3] - 2026-04-28

### Added

- M-Bus Header autodiscovery for Home Assistant (all 4 variants)
- Header fields published via MQTT with type-aware loops
- Depends on MBusinoLib 0.9.20 (a_field → address)

## [1.0.2] - 2026-04-01

### Fixed

- W5500 Ethernet auto-negotiation: disable auto-negotiation and force 10BASE-T full-duplex before each ETH.begin() call. Fixes connection failures with strict gigabit equipment (Fritzbox 7590, PoE extenders, managed switches). Applied to MBusinoNano and MBusinoNano5S.

### Changed

- Updated binary files for MBusinoNano and MBusinoNano5S (C3 SuperMini)

## [1.0.1] - 2026-03-20

### Changed

- Buffer safety and code clarity improvements (all firmware variants)
- Merged LED flash for AP mode from upstream
- Compiled all firmware variants with ESP32Async libraries (ESP Async WebServer 3.10.3, Async TCP 3.4.10)
- Updated binary files for all boards

### Dependencies

- MBusinoLib 0.9.16
- MBusCom 0.1.6
- ArduinoJson 7.4.3
- ESP Async WebServer 3.10.3 (ESP32Async)
- Async TCP 3.4.10 (ESP32Async)
- ESP Async TCP 2.0.0 (ESP8266 only)

## [1.0.0] - 2026-01-13

### Changed

- Assigning all allowed M-Bus addresses (0-250) is now possible in the 5S firmware.
- credentials storrages (SSID,Password, Broker, MQTT-Pasword and User) are now 64 characters long.

## [0.9.24] - 2026-01-08

### Changed

- HA audodicovery, change "object_id":"xxx" "default_entity_id":"sensor.xxx"

## [0.9.23] - 2025-09-11

### Changed

- increase name variable at ha audodicovery
- MBusinoLib 0.9.15

## [0.9.22b] - 2025-07-23

### Changed

- little bugfix MBusino5S Sensor8
- all Files still 0.9.22

## [0.9.22] - 2025-07-21

### Changed

- MBusinoLib 0.9.14
- DS18B20 S6 with ESP32 S2 issue fixed

### Added

- Support of Slaves with multible response telegrams

## [0.9.21] - 2025-05-01

### Changed

- MBusinoLib 0.9.12
- Support for 5 Slaves (5S)

### Added

- MBusino Nano with Ethernet

## [0.9.20] - 2025-03-28

### Changed

- Improved WiFi stability for S2 mini (prevents crashes)

## [0.9.19] - 2025-02-27

### Changed

- Sourced the M-Bus communication out to a Arduino IDE accessable Library --> MBusCom

## [0.9.18] - 2025-02-16

### Changed

- rename outsourced code for the GUI-Server from server.h to guiServer.h because of Windows Compiling issues. (.bin files are not changed and sill 0.9.17)

### Added

- case file for Z-Version

## [0.9.17] - 2025-02-06

### Added

- MQTT topic FreeHeap

## [0.9.16] - 2025-01-30

### Changed

- fixed again problems with the webserver since 0.9.14

## [0.9.15] - 2025-01-28

### Changed

- fixed problems with the webserver since 0.9.14

## [0.9.14] - 2025-01-27

### Changed

- MBusinoLib 0.9.9
- changed the server syntax because of a new release of ESPasyncWebServer 
- Stop the whole main loop if the WIFI and MQTT connection is lost.

## [0.9.13] - 2025-01-13

### Changed

- MBusinoLib 0.9.8

## [0.9.12] - 2025-01-04

### Added

- M-Bus request polling per MQTT

## [0.9.11] - 2024-12-03

### Changed

- increased time between M-Bus request and get response for slow slaves 
- placed sensor1.setWaitForConversion(false) etc. to the right place, to set the OneWire communication async
- changed the BME280 topics to english language
- tutorial: add links to the .bin files

## [0.9.10] - 2024-11-16

### Changed

- increased size of jsonstring to 4092 
- add a GUI selection for raw telegram output to debug (only for MBusino)

## [0.9.9] - 2024-11-05

### Changed

- update to MBusinoLib 0.9.7 - HA Autodiscovery StateClass TOTAL for Energy

## [0.9.8] - 2024-06-21

### Changed

- hide MQTT Password

## [0.9.7] - 2024-05-14

### Added

- a switch for Homeassitant autodiscovery messages.

## [0.9.6] - 2024-05-14

### Added

- retained flag for Homeassitant autodiscovery messages.

## [0.9.5] - 2024-04-16

### Changed

- roll back from float to double for a better precision

## [0.9.4] - 2024-04-15

### Changed

- separate decodeing and sending of records for a better stability

- length of form text fields in html are now limited to the length of the variable

## [0.9.3] - 2024-04-11

### Added

- better real support

- support for more as one VIFEs

## [0.9.1] - 2024-03-12

### Added

- Home Assistant autodiscovery for MBusino3S. 

## [0.9.0] - 2024-03-11

### Added

- Home Assistant autodiscovery for MBusino. 

## [0.8.0] - 2024-02-26

### Added

- ESP32 S2 mini is now supported

- ESP32 S2 mini flashing tutorial.

### Changed

- Some improfements at Readme and tutorials

## [0.7.2] - 2024-02-22

### Added

- M-Bus Address

### Changed

- MBusinoAP with Accesspoint is now standard, renamed to MBusino. Old MBusino code without accesspoint is in archive

- Split the MBusino code in deferent .h files for a better clarity  

- English tutorial

- Some improfements at Readme and german tutorial

## [0.7.1] - 2024-01-31

### Changed

- new MBusino own http updater

## [0.7.0] - 2024-01-30
- Initial version with releases and changelog

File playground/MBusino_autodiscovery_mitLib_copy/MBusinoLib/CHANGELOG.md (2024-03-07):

# MBusinoLib change log

The format is based on [Keep a Changelog](http://keepachangelog.com/)
and this project adheres to [Semantic Versioning](http://semver.org/).

## [0.7.1] - 2024-02-26

### Changed

- delete unused files in example

## [0.7.0] - 2024-02-26

### Added

- Added a much simpler example 

### Changed

- Typos in code: Year JJ --> YY

## [0.6.1] - 2024-01-28

### Changed

- Switch to ArduinoJSON 7

## [0.6.0] - 2024-01-19

### Added

- support of "Codes for Value Information Field Extension (VIFE)" other then 0xFB,0xFC and 0xFD. Only to prevent stumbling, not all Units are implemented 

## [0.5.3] - 2023-12-16

### Solved

- compilation problems at Windows machines

## [0.5.2] - 2023-12-13

### Changed

- revised documentation

## [0.5.1] - 2023-12-12

### Changed

- typing error correction

## [0.5.0] - 2023-12-12

### Added

- support sub unit, tariff and storage number

### Changed

- send only important and existing values to the json to save storage

## [0.4.0] - 2023-12-12

### Added

- support for variable length values included ASCII values

## [0.3.0] - 2023-12-04

### Changed

- delete all encode capabilities.

## [0.2.0] - 2023-11-28

### Added

- support for customized ASCII VIF 0hFC 

### Changed

- some tab format for a better clarity.

## [0.1.0] - 2023-11-21
- Initial version

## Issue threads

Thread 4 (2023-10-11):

Link for piggyback PCB may be incorrect, not the same board as shown

dirkvdb2, 2023-10-11:
"Das Shield ist ein mit Fritzing konstruiertes Board. Der M-Bus wird über einen aufsteckbaren M-Bus Master bereitgestellt. https://de.aliexpress.com/item/33008746192.html --> der Master!"

This link points to a different board with at least partielly different pinning (only two pins for MBUS.
I found offers on aliexpress to the correct board, eg.:
https://www.aliexpress.com/item/1005004664326197.html?spm=a2g0o.cart.0.0.140338dajc8E4F&mp=1

Zeppelin500, 2023-10-11:
Yes, but you will receive a board with 6 pins.
But If you receive a board with only two pins at the MBus side, it will work also. Every 3 pins are connected.

Zeppelin500, 2024-01-09:
Add a hint at the readme

Closed 2024-01-09.

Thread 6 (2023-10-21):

One OneWire bus to rule them all

rschiemann1, 2023-10-21:
As pointed out in discussion #3, we could  start using one oneWire-Bus for all oneWire sensors that one would like to connect to MBusino. This is much different to the current implementation, which has 5 separated oneWire buses (with 5 GPIOs on their data lines).

Advantages:

- arbitrarily many oneWire sensors can be connected to MBusino
- Only one GPIO is used instead of 5

Disadvantages:
- Software needs to handle multiple sensors on the same bus and possibly their adresses
- Somewhat more difficult mapping of sensor values to physical sensors by the end user

Some preliminary ideas for the realization:
1. MBusino could scan the oneWire bus for all connected sensors and their adresses once per boot, or additionally upon request, if needed. From each sensor's adress, a sensor ID is derived, which could read "28-28B1-970E-0000" for example.
2. For each discovered sensor, two mqtt topics are created: mbusino/[sensorID]/measuredValue and mbusino/[sensorID]/offset. Offset can be set via mqtt from the outside to calibrate sensors.
3. Above logic should create a working system without the need to somehow hardcode sensor adresses.

Open questions:
1. Do we need/want to save the known adresses of the sensors to the EEPROM and re-use them on next boot? Is this solution any better than just scanning the bus once per boot?
2. Do we need/want to save the offset values for each sensor to the EEPROM and re-use them on next boot? If yes, how do map in the EEPROM to which sensor ID an offset value belongs to? If no, the offset values need to come from the mqtt broker on the next startup, which can be realized by making these topics retained.

Please let me know your comments, ideas, doubts.

Zeppelin500, 2023-11-08:
Answer, see discussions (in german only)

Closed 2024-01-09.

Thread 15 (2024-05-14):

Using more than three slaves

cryptomulde, 2024-05-14:
Hello,

thank you for the solution. It is exactly what I am looking for and helps me get my planned meters into HA.

I want to setup my house using four Engelmann Sensostar U. (Basement --> start, ground floor, first floor, second floor)

In the readme it says we are limited to three devices? What causes these limitations? Could it be avoided or do I just setup a secondary esp to tackle the problem?

Zeppelin500, 2024-05-15:
The limitation is from the M-Bus Master (and from the Code, but can be changed). The master provides the slaves with power.
A tiny DC/DC converter converts 5V to 36V. The limitation of 3 is only estimated. Nobody has tested yet. You can try it, **but I recommend two M-Businos**.
Another problem ist that the time between the requests (min. ~5sec.)will be added per slave.

You can also try the Zihatec Master. Specification says max. 6 Slaves. But the Zihatec Master need a additional power supply and will not fit mechanically to MBusino. Also you has to use an ESP32 S2 mini, because the serial of ESP 8266 and the Zihatec Master are no friends.

cryptomulde, 2024-05-17:
Thank you for your detailed explanation. I adapted the setup so I will only use three meters.

I want to setup the following way:

"primary-wire" roof-meter running to first-floor-meter --> first-floor-meter --> basement (wago)

"secondary-wire" ground-floor meter --> basement (wago)

Can I connect primary and secondary wire in a wago and connect the whole bunch to mbusino?

Would this still be considered a daisy chain or do I have to run in a row --> roof --> first floor --> ground floor --> mbusino?

Zeppelin500, 2024-05-17:
See chapter 2.5, the wiring doesn't matter.
https://www.google.com/url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

Closed 2024-06-27.

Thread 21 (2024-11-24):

How to build within Arduino IDE?

baycom, 2024-11-24:
As a PlatformIO user I am trying to compile the project with the Arduino IDE. After setting my ESP32 board type, adding all libraries manually and clicking on 'verify' I get errors like these:
.../proj/MBusino/src/MBusino/Server.h: In function 'void setupServer()':
.../proj/MBusino/src/MBusino/Server.h:2:3: error: 'server' was not declared in this scope; did you mean 'Server'?

Is there any document describing how to properly build this project?

Zeppelin500, 2024-11-24:
Mh, do you use Arduino IDE 2?
Yes, it's a weakness of Arduino IDE, that you can't specify the exact libraries.
But I think, server.h is only one part of my outsourced  code parts in src.
All my used Libraries are the newest from the Library Manager beside "ESPAsyncWebServer", use my version. Because the version in the manager is not longer compatible to the esp core code.
Gruß Zeppelin

Zeppelin500, 2025-02-12:
Its a Problem of Windows. Upper and lower case letters are ignored. I use Linux, so I has no problem there. server.h already changed to guiServer.h

Closed 2025-02-16.

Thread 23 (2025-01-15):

M-Bus with multiple Slaves

Axel-Knauff, 2025-01-15:
I want to use the M-Bus with two Kamstrup heat meters.
M-Bus runs perfect with only one slave. No matter which one of both I connect.
When I try to use it with two slaves, each with different addresses (196 and 183) I only get the response of one slave.  And an error message of the other.

I would appreciate if the M-Bus would deliver the results of all slaves that are connected to the bus.

I thought about building a second controller set, but it seems to be a waist of resources.

I use the actual version 0.9.12
Only the M-Bus is connected and configured in the setup

thenebu, 2025-01-15:
Do you use the 3S version?

Axel-Knauff, 2025-01-15:
No I use the standard ESP8266 version Am 15.01.2025 um 12:30 schrieb thenebu ***@***.***>:
Do you use the 3S version?

—Reply to this email directly, view it on GitHub, or unsubscribe.You are receiving this because you authored the thread.Message ID: ***@***.***>

thenebu, 2025-01-15:
Standard version can only handle one slave. You need to 3S version. it’s for up to 3 slaves
I use a esp32 s2 with 2 slaves

Axel-Knauff, 2025-01-15:
Perfect. The 3S is already ordered.
Thank You
Axel

Zeppelin500, 2025-01-15:
> Perfect. The 3S is already ordered. Thank You Axel

Ordered? Its just a different Firmware. Go to your GUI --> Update. Und Flash the MBusino3S Firmware. Tutorial will help.

Axel-Knauff, 2025-01-15:
Sorry, the ESP S2 CPU is ordered. The S3 firmware is now installed on the ESP 8266 and works fine.

Zeppelin500, 2025-01-15:
Yes, 8266 work fine. ESP32 S2 Mini ist only necessary for the Zihatec Master. Because the Serial UART of the 8266  won't work together with the Zihatec Master.

Closed 2025-01-24.

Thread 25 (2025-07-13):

Nearly no / no stable DS18B20 over MQTT

michas79de, 2025-07-13:
I want to prepare the MBusino for use in another house as much as possible.
Since I don't have an MBUS client here yet (it's in the other house), I tried some temp sensors without success.

In detail:

The parts I have are:
PCB MBusino PCB "edition Z"
ESP32 S2 mini
(M-Bus master from Zihatec)
5x DS18B20
(Raspberry Pi 1 mod. B)

I tested all the DS18B20s (in groups of three and two) with the Pi and had success:
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

All five DS18B20s are screwed directly to the PCB again.
When I connect the S2 Mini to a USB port, a blue light turns on for about two or three seconds after about five seconds, and then it starts flashing at about 10 Hz.

The MBusino is connected to my Wi-Fi, and I can see it in the router's GUI. I can also open the MBusino setup GUI. The Wi-Fi used is Wi-Fi 4, with less than 3 meters to the router and a signal strength of -54 dBm, and it is connected to an MQTT broker (the Mosquitto broker add-on in Home Assistant, which is on the same local network, but by wire/ethernet cable).

After running for a while with the MQTT5 Explorer open, I only see two sensors this time.
Sometimes I see three or four sensors, sometimes one or none, but never all five!
Even after more than 50 minutes, there were only two messages per sensor.
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

the setup:
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

When I run Arduino IDE 2.3.6 with the MBusino connected, I don't see any useful information.
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

I want to prepare the MBusino by testing it with the DS18B20. Later, I will replace the DS18B20 with the M-Bus master from Zihatec and update the setup. I will send the MBusino to my 78-year-old dad in the other house. He will just need to add the two MBus wires and USB power.
I have two main thoughts/questions:  I wonder if
- There will be a similar issue with the MBus, and if
- This issue with the DS18B20 may just be a software bug that doesn't need to bother me much more.

Regarding the latter: Can I display more information in the Arduino IDE? Or, is there another way to access the sensor data before it is processed and sent to MQTT?

michas79de, 2025-08-03:
After double checking everything, the issue couldn't be solved.
But since this was just to prepare for plug'n'play MBUS use, it doesn't matter to me.
Meanwhile, the hardware is in the other house, connected by my dad, and seems to work fine with MBUS (only) now.

@Zeppelin500 Feel free to close this one as _can't repro_ for example.

Closed 2025-08-04.

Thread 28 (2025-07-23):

BME280 shows no values with 0.9.22

elodur, 2025-07-23:
**Describe the bug**
BME280 sensor is not updated any more since I installed version 0.9.22. MBus devices still work fine.

**To Reproduce**
Steps to reproduce the behavior:
1. install mbusino5s v 0.9.22
2. don't get any values from BME280

**Expected behavior**
New data from sensor.

I already tryed to reconfigure Mbusino (sensor on, off, on again), didn't help.

elodur, 2025-07-23:
Mbusino5S.

elodur, 2025-07-23:
Solved, works flawless again. Thanks a lot!

Closed 2025-07-23.

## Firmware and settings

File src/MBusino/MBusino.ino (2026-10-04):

/*
# MBusino: M-Bus/OneWire/I²C --> MQTT-Gateway with a shield for ESP8266 D1 mini or ESP32 S2 mini

https://github.com/Zeppelin500/MBusino/

## Licence
****************************************************
This program is free software: you can redistribute it and/or modify it under the terms of the GNU General Public License as published by
the Free Software Foundation, either version 3 of the License, or (at your option) any later version. This program is distributed in the hope that it will be useful,
but WITHOUT ANY WARRANTY; without even the implied warranty of MERCHANTABILITY or FITNESS FOR A PARTICULAR PURPOSE.  See the GNU General Public License for more details.
You should have received a copy of the GNU General Public License along with this program.  If not, see <http://www.gnu.org/licenses/>.
****************************************************
*/

#include <Arduino.h>
#include <PubSubClient.h>
#include <OneWire.h>            // Library for OneWire Bus
#include <DallasTemperature.h>  //Library for DS18B20 Sensors
#include <Wire.h>
#include <ESPAsyncWebServer.h> 

#include <DNSServer.h>
#include <ArduinoOTA.h>
#include <MBusinoLib.h>  // Library for decode M-Bus
#include <MBusCom.h>  // Library M-Bus communication
#include <ArduinoJson.h>
#include <EEPROM.h>

#include <Adafruit_Sensor.h>
#include <Adafruit_BME280.h>

#if defined(ESP8266)
#include <ESP8266WiFi.h>
#include <ESPAsyncTCP.h>
MBusCom mbus(&Serial);
#elif defined(ESP32)
#include <WiFi.h>
#include <AsyncTCP.h>
HardwareSerial MbusSerial(1);
MBusCom mbus(&MbusSerial,37,39);
#endif

#define MBUSINO_VERSION "1.1.2"

#define MBUS_ADDRESS 254

// EEPROM flag constants
#define EEPROM_CALIBRATED_FLAG 500
#define EEPROM_CREDENTIALS_OLD 500
#define EEPROM_CREDENTIALS_NEW 501

#if defined(ESP8266)
#define ONE_WIRE_BUS1 2   //D4
#define ONE_WIRE_BUS2 13  //D7
#define ONE_WIRE_BUS3 12  //D6
#define ONE_WIRE_BUS4 14  //D5
#define ONE_WIRE_BUS5 0   //D3
#define ONE_WIRE_BUS6 5   //D1
#define ONE_WIRE_BUS7 4   //D2
#elif defined(ESP32)
#define ONE_WIRE_BUS1 16 //2   //D4
#define ONE_WIRE_BUS2 11  //13  //D7
#define ONE_WIRE_BUS3 9   //12  //D6
#define ONE_WIRE_BUS4 7   //14  //D5
#define ONE_WIRE_BUS5 18  //0   //D3
#define ONE_WIRE_BUS6 35  //5   //D1
#define ONE_WIRE_BUS7 33  //4   //D2
#endif

#define SEALEVELPRESSURE_HPA (1013.25)
Adafruit_BME280 bme;  // I2C
MBusinoLib payload(254);
WiFiClient espClient;
PubSubClient client(espClient);
DNSServer dnsServer;
AsyncWebServer server(80);
AsyncWebSocket ws("/ws"); // access at ws://[esp ip]/ws
AsyncEventSource events("/events"); // event source (Server-Sent events)

// Setup a oneWire instance to communicate with any OneWire devices (not just Maxim/Dallas temperature ICs)
OneWire oneWire1(ONE_WIRE_BUS1);
OneWire oneWire2(ONE_WIRE_BUS2);
OneWire oneWire3(ONE_WIRE_BUS3);
OneWire oneWire4(ONE_WIRE_BUS4);
OneWire oneWire5(ONE_WIRE_BUS5);

OneWire oneWire6(ONE_WIRE_BUS6);
OneWire oneWire7(ONE_WIRE_BUS7);


// Pass our oneWire reference to Dallas Temperature.
DallasTemperature sensor1(&oneWire1);
DallasTemperature sensor2(&oneWire2);
DallasTemperature sensor3(&oneWire3);
DallasTemperature sensor4(&oneWire4);
DallasTemperature sensor5(&oneWire5);

DallasTemperature sensor6(&oneWire6);
DallasTemperature sensor7(&oneWire7);

struct settings {
  char ssid[65];
  char password[65];
  char mbusinoName[31];
  char broker[65];
  uint16_t mqttPort;
  uint16_t extension;
  char mqttUser[65];
  char mqttPswrd[65]; 
  uint32_t sensorInterval;
  uint32_t mbusInterval; 
  bool haAutodisc;
  bool telegramDebug;
} userData = {"SSID","Password","MBusino","192.168.1.8",1883,5,"mqttUser","mqttPassword",5000,120000,true,false};

struct oldSettings {
  char ssid[30];
  char password[30];
  char mbusinoName[11];
  char broker[20];
  uint16_t mqttPort;
  uint16_t extension;
  char mqttUser[30];
  char mqttPswrd[30]; 
  uint32_t sensorInterval;
  uint32_t mbusInterval; 
  bool haAutodisc;
  bool telegramDebug;
} oldUserData = {"SSID","Password","MBusino","192.168.1.8",1883,5,"mqttUser","mqttPassword",5000,120000,true,false};

bool mqttcon = false;
bool apMode = false;
bool credentialsReceived = false;
uint16_t conCounter = 0;

int Startadd = 0x13;  // Start address for decoding

float OW[7] = {0};         // variables for DS18B20 Onewire sensors 
float temperatur = 0;      // Variablen für den BLE280 am I2C
float druck = 0;
float hoehe = 0;
float feuchte = 0;
bool bmeStatus;
uint8_t sensorStatus = 0;

uint8_t mbusLoopStatus = 0;
uint8_t fields = 0;
bool fcb = 0; // M-Bus Frame Count Bit
bool initializeSlave = true; // m-bus normalizing is needed
uint8_t recordCounter = 0; // count the received records for multible telegrams
char jsonstring[4096] = { 0 };
bool engelmann = false;
bool waitForRestart = false;
bool polling = false;
bool wifiReconnect = false;
bool ledStatus = false;

unsigned long timerMQTT = 15000;
unsigned long timerSensorRefresh1 = 0;
unsigned long timerSensorRefresh2 = 0;
unsigned long timerMbus = 0;
unsigned long timerSerialAvailable = 0;
unsigned long timerMbusDecoded = 0;
unsigned long decodingTime = 0;
unsigned long timerMbusReq = 0;
unsigned long timerDebug = 0;
unsigned long timerReconnect = 0;
unsigned long timerWifiReconnect = 0;
unsigned long timerReboot = 0;
unsigned long timerAutodiscover = 0;
unsigned long timerPulse = 0;

void mbus_request_data(byte address);
void mbus_short_frame(byte address, byte C_field);
bool mbus_get_response(byte *pdata, unsigned char len_pdata);
void calibrationAverage();
void calibrationSensor(uint8_t sensor);
void calibrationValue(float value);
void calibrationSet0();
void calibrationBME();
void setupServer();

uint8_t eeAddrCalibrated = 0;
uint8_t eeAddrCredentialsSaved = 32;
uint8_t eeAddrOffset[7] = {4,8,12,16,20,24,28};  //EEPROM address to start reading from
uint16_t calibrated = 123;  // shows if EEPROM used befor for offsets
uint16_t credentialsSaved = 123;  // shows if EEPROM used befor for credentials
float offset[7] = {0};
float OWwO[7] = {0};  // Variables for DS18B20 Onewire Sensores with Offset (One Wire1 with Offset)
bool OWnotconnected[7] = {false};
uint8_t sensorToCalibrate = 0;


uint8_t adMbusMessageCounter = 0; // Counter for autodiscouver mbus message.
uint8_t adSensorMessageCounter = 0; // Counter for autodiscouver mbus message.

uint32_t minFreeHeap = 0;
uint16_t pulseInterval = 1000;

//outsourced program parts
#include "html.h"
#include "calibration.h"
#include "sensorRefresh.h"
#include "mqtt.h"
#include "guiServer.h"
#include "autodiscover.h"
#if defined(ESP32)
#include "networkEvents.h"
#endif

void setup() {
  #if defined(ESP32)
  pinMode(LED_BUILTIN, OUTPUT);
  Serial.begin(115200);
  delay(1500);
  #endif
  mbus.begin();

  minFreeHeap = ESP.getFreeHeap();

  EEPROM.begin(512);
  EEPROM.get(eeAddrCalibrated, calibrated);
  
  if(calibrated==EEPROM_CALIBRATED_FLAG){ // if EEPROM_CALIBRATED_FLAG the EEPROM is not used before and full of junk
    for(uint8_t i = 0; i <=userData.extension; i++){
      EEPROM.get(eeAddrOffset[i], offset[i]);
    }
  }
  else{
      for(uint8_t i = 0; i < 7; i++){    
        EEPROM.put(eeAddrOffset[i], 0);  // copy offset 0 to EEPROM
      }
      calibrated = EEPROM_CALIBRATED_FLAG;
      EEPROM.put(eeAddrCalibrated, calibrated);  // copy the key to EEPROM that the EEPROM is written and not full of junk.
  }
  EEPROM.get(eeAddrCredentialsSaved, credentialsSaved);
  if(credentialsSaved == EEPROM_CREDENTIALS_OLD){  // Old version before 1.0 (size of some variables has changed)
    EEPROM.get(100, oldUserData );
    strncpy(userData.ssid, oldUserData.ssid, sizeof(userData.ssid) - 1);
    strncpy(userData.password, oldUserData.password, sizeof(userData.password) - 1);
    strncpy(userData.mbusinoName, oldUserData.mbusinoName, sizeof(userData.mbusinoName) - 1);
    strncpy(userData.broker, oldUserData.broker, sizeof(userData.broker) - 1);
    userData.mqttPort = oldUserData.mqttPort;
    userData.extension = oldUserData.extension ;
    strncpy(userData.mqttUser, oldUserData.mqttUser, sizeof(userData.mqttUser) - 1);
    strncpy(userData.mqttPswrd, oldUserData.mqttPswrd, sizeof(userData.mqttPswrd) - 1);
    userData.sensorInterval= oldUserData.sensorInterval;
    userData.mbusInterval = oldUserData.mbusInterval; 
    userData.haAutodisc = oldUserData.haAutodisc;
    userData.telegramDebug = oldUserData.telegramDebug;

    EEPROM.put(100, userData);
    credentialsSaved = EEPROM_CREDENTIALS_NEW;
    EEPROM.put(eeAddrCredentialsSaved, credentialsSaved);
  }
  else if(credentialsSaved == EEPROM_CREDENTIALS_NEW){  // Version after 1.0 (size of some variables has changed)
    EEPROM.get(100, userData );
  }

  EEPROM.commit();
  EEPROM.end();

  if(userData.telegramDebug > 1){
    userData.telegramDebug = 0;
  }

  snprintf(html_buffer, sizeof(html_buffer), index_html,userData.ssid,userData.mbusinoName,userData.extension,userData.haAutodisc,userData.telegramDebug,userData.sensorInterval/1000,userData.mbusInterval/1000,userData.broker,userData.mqttPort,userData.mqttUser);
  
  #if defined(ESP32)
  WiFi.onEvent(WiFiEvent);
  #endif
  WiFi.hostname(userData.mbusinoName);
  client.setServer(userData.broker, userData.mqttPort);
  client.setCallback(callback);

  WiFi.mode(WIFI_STA);
  WiFi.begin(userData.ssid, userData.password);

  byte tries = 0;
  while (WiFi.status() != WL_CONNECTED) {
    delay(1000);
    if (tries++ > 10) {
      WiFi.mode(WIFI_AP);
      WiFi.softAP("MBusino Setup Portal"); //, "secret");
      apMode = true;
      break;
    }
  }
  setupServer();
  if(apMode==true){
    dnsServer.start(53, "*", WiFi.softAPIP());
  }
  server.addHandler(new CaptiveRequestHandler()).setFilter(ON_AP_FILTER);//only when requested from AP

  //attach AsyncWebSocket
 // ws.onEvent(onEvent);
  server.addHandler(&ws);

  // attach AsyncEventSource
  server.addHandler(&events);

  // Simple Firmware Update Form
  server.on("/update", HTTP_GET, [](AsyncWebServerRequest *request){
    request->send(200, "text/html",  (uint8_t *)update_html, update_htmlLength);  
  });
  server.on("/update", HTTP_POST, [](AsyncWebServerRequest *request){
    waitForRestart = !Update.hasError();
    if(Update.hasError()==true){
      timerReboot = millis();
    }
    AsyncWebServerResponse *response = request->beginResponse(200, "text/plain", waitForRestart?"success, restart now":"FAIL");
    response->addHeader("Connection", "close");
    request->send(response);
  },[](AsyncWebServerRequest *request, String filename, size_t index, uint8_t *data, size_t len, bool final){
    if(!index){
      #if defined(ESP8266)
      Update.runAsync(true);
      #endif
      if(!Update.begin((ESP.getFreeSketchSpace() - 0x1000) & 0xFFFFF000)){
        Update.printError(Serial);
      }
    }
    if(!Update.hasError()){
      if(Update.write(data, len) != len){
        Update.printError(Serial);
      }
    }
    if(final){
      if(Update.end(true)){
        Serial.printf("Update Success: %uB\n", index+len);
      } else {
        Update.printError(Serial);
      }
    }
  });
  ArduinoOTA.setPassword((const char *)"mbusino");
  server.onNotFound(onRequest);
  #if defined(ESP8266)
  ArduinoOTA.begin(&server);
  #elif defined(ESP32)
  ArduinoOTA.begin();
  #endif
  server.begin();

  client.setBufferSize(6000);

  // Start up the library
  if(userData.extension > 0){
    sensor1.begin();
    sensor2.begin();
    sensor3.begin();
    sensor4.begin();
    sensor5.begin();
    
    sensor1.setWaitForConversion(false);  // Request temperature conversion - non-blocking / async
    sensor2.setWaitForConversion(false);
    sensor3.setWaitForConversion(false);
    sensor4.setWaitForConversion(false);
    sensor5.setWaitForConversion(false);
  }
  if(userData.extension == 7){
    sensor6.begin();
    sensor7.begin();

    sensor6.setWaitForConversion(false);
    sensor7.setWaitForConversion(false);    
  }

  if(userData.extension == 5){
    // Vorbereitungen für den BME280
    bmeStatus = bme.begin(0x76);
  }

}


void loop() {
  heapCalc();
  ArduinoOTA.handle();
  if(apMode == true){
    dnsServer.processNextRequest();
  }

  #if defined(ESP32)
  if(millis() - timerPulse >= pulseInterval){ // Blink of the internal LED to see MBusino is still alive and the network status
    timerPulse = millis();
    //Serial.println("pulse"); 
    if(ledStatus == false){
      ledStatus = true;
      digitalWrite(LED_BUILTIN, HIGH);
    }else{
      ledStatus = false;
      digitalWrite(LED_BUILTIN, LOW);
    }
  }

  if(wifiReconnect == true && (millis() - timerWifiReconnect > 2000)){
    Serial.println("try to reconnect"); 
    wifiReconnect = false;
    WiFi.reconnect();
  }
  #endif

  if(apMode == true && millis() > 300000){
    ESP.restart();
  }

  if(credentialsReceived == true && waitForRestart == false){
    EEPROM.begin(512);
    EEPROM.put(100, userData);
    credentialsSaved = EEPROM_CREDENTIALS_NEW;
    EEPROM.put(eeAddrCredentialsSaved, credentialsSaved);
    EEPROM.commit();
    EEPROM.end();
    timerReboot = millis();
    waitForRestart = true;
  }

  if(waitForRestart==true && (millis() - timerReboot) > 1000){
    ESP.restart();
  }

  if(WiFi.status() == WL_CONNECTED && apMode == false){
    if (!client.connected()) { 
      if((millis() - timerReconnect) > 5000){
        reconnect();
        timerReconnect = millis();
      }
    }
    else{ // the whole main code run only if MQTT is connectet
      client.loop();  //MQTT Funktion

      ///////////////// publish settings ///////////////////////////////////
      if((millis()-timerDebug) >10000){
        timerDebug = millis();
        client.publish(String(String(userData.mbusinoName) + "/settings/ssid").c_str(), userData.ssid); 
        //client.publish(String(String(userData.mbusinoName) + "/settings/password").c_str(), String(userData.password)); 
        client.publish(String(String(userData.mbusinoName) + "/settings/broker").c_str(), userData.broker); 
        client.publish(String(String(userData.mbusinoName) + "/settings/port").c_str(), String(userData.mqttPort).c_str()); 
        client.publish(String(String(userData.mbusinoName) + "/settings/user").c_str(), userData.mqttUser); 
        //client.publish(String(String(userData.mbusinoName) + "/settings/pswd").c_str(), userData.mqttPswrd); 
        client.publish(String(String(userData.mbusinoName) + "/settings/name").c_str(), userData.mbusinoName); 
        client.publish(String(String(userData.mbusinoName) + "/settings/extension").c_str(), String(userData.extension).c_str()); 
        client.publish(String(String(userData.mbusinoName) + "/settings/mbusInterval").c_str(), String(userData.mbusInterval).c_str()); 
        client.publish(String(String(userData.mbusinoName) + "/settings/sensorInterval").c_str(), String(userData.sensorInterval).c_str());     
        client.publish(String(String(userData.mbusinoName) + "/settings/IP").c_str(), String(WiFi.localIP().toString()).c_str());
        client.publish(String(String(userData.mbusinoName) + "/settings/MQTTreconnections").c_str(), String(conCounter-1).c_str());
        long rssi = WiFi.RSSI();
        client.publish(String(String(userData.mbusinoName) + "/settings/RSSI").c_str(), String(rssi).c_str()); 
        client.publish(String(String(userData.mbusinoName) + "/settings/version").c_str(), MBUSINO_VERSION);  
        client.publish(String(String(userData.mbusinoName) + "/settings/freeHeap").c_str(), String(ESP.getFreeHeap()).c_str()); 
        client.publish(String(String(userData.mbusinoName) + "/settings/minFreeHeap").c_str(), String(minFreeHeap).c_str()); 
      }
      ///////////////////////////////////////////////////////////
      

      if(userData.extension > 0){      
        switch(sensorStatus){
          case 0:
            if((millis() - timerMQTT) > userData.sensorInterval) { // springt in die Funktion zum anstoßen der aktuallisierung der Sensorwerte
              sensorRefresh1();
              timerMQTT = millis();
              sensorStatus = 1;
              timerSensorRefresh1 = millis();
            }
            break;
          case 1:
            if ((millis() - timerSensorRefresh1) > 800) {  // springt in die Funktion zum holen der neuen Sensorwerte
              sensorRefresh2();
              timerSensorRefresh1 = millis();
              sensorStatus = 2;
            }
            break;
          case 2:
            if((millis() - timerSensorRefresh1) > 200){
              adSensorMessageCounter++;
              for(uint8_t i = 0; i < userData.extension; i++){
                if(OW[i] != -127){        
                  client.publish(String(String(userData.mbusinoName) + "/OneWire/S" + String(i+1)).c_str(), String(OWwO[i]).c_str());
                  client.publish(String(String(userData.mbusinoName) + "/OneWire/offset" + String(i+1)).c_str(), String(offset[i]).c_str());
                  if(userData.haAutodisc == true && adSensorMessageCounter == 3){
                    haHandoverOw(i+1);
                  }          
                }      
              }
            
              if(userData.extension == 5){
                client.publish(String(String(userData.mbusinoName) + "/bme/temperature").c_str(), String(temperatur).c_str());
                client.publish(String(String(userData.mbusinoName) + "/bme/pressure").c_str(), String(druck).c_str());
                client.publish(String(String(userData.mbusinoName) + "/bme/altitude").c_str(), String(hoehe).c_str());
                client.publish(String(String(userData.mbusinoName) + "/bme/humidity").c_str(), String(feuchte).c_str());
                if(userData.haAutodisc == true && adSensorMessageCounter == 3){
                  haHandoverBME();
                }
              }
            sensorStatus = 0;
            }
            break;
        }
      }
      ////////// M- Bus ###############################################

      if(initializeSlave == true){
        initializeSlave = false;
        mbus.normalize(MBUS_ADDRESS);
        timerMbus = millis();
      }
      /*
      mbusLoopStatus
      0 = request the records from the slave
      1 = wait for response of the slave
      2 = get response from the rx buffer and decode the telegram
      3 = Send decoded M-Bus secords via MQTT
      */


      switch(mbusLoopStatus){
        case 0:
          if((millis() - timerMbus > userData.mbusInterval || polling == true) && mbusLoopStatus == 0){ // Request M-Bus Records
            if(polling == false){ // if polling is true or a following telegram of a multi telegram, dont touch the timer
              timerMbus = millis();
            }
            polling = false;
            mbusLoopStatus = 1;
            mbus.clearRXbuffer();
            mbus.request_data(MBUS_ADDRESS, fcb);
            timerMbusReq = millis();
          }
          break;
        case 1:    
          if(mbus.available()){
            mbusLoopStatus = 2;
            timerSerialAvailable = millis();
          }
          if(millis() - timerMbusReq > 2000){ // failure, no data received
            initializeSlave = true;
            recordCounter = 0;
            fcb = false;              
            client.publish(String(String(userData.mbusinoName)  +"/MBus/MBUSerror").c_str(), "no_Data_received");
            mbusLoopStatus = 0;
            polling = false;
          }
          break;

        case 2:  
          if((millis() - timerSerialAvailable) > 1500){ // Receive and decode M-Bus Records
          decodingTime = millis();
          mbusLoopStatus = 3;
          bool mbus_good_frame = false;
          byte mbus_data[MBUS_DATA_SIZE] = { 0 };
          mbus_good_frame = mbus.get_response(mbus_data, sizeof(mbus_data));

          //bool mbus_good_frame = true;
          //byte mbus_data[] = {0x68,0x9E,0x9E,0x68,0x08,0x65,0x72,0x09,0x76,0x06,0x00,0xA5,0x25,0x1D,0x02,0x02,0x00,0x00,0x00,0x85,0x40,0xAB,0xFF,0x01,0x00,0x36,0x0B,0x47,0x85,0x40,0xAB,0xFF,0x02,0x00,0x2C,0xFA,0x46,0x85,0x40,0xAB,0xFF,0x03,0x00,0x74,0xED,0x46,0x85,0x80,0x40,0xAB,0xFF,0x01,0x00,0xC0,0xE2,0x44,0x85,0x80,0x40,0xAB,0xFF,0x02,0x00,0x40,0x5A,0x45,0x85,0x80,0x40,0xAB,0xFF,0x03,0x00,0x60,0x36,0x45,0x05,0xFD,0xBA,0xFF,0x01,0x78,0xBE,0x7F,0x3F,0x05,0xFD,0xBA,0xFF,0x02,0x40,0x35,0x7E,0x3F,0x05,0xFD,0xBA,0xFF,0x03,0x53,0xB8,0x7E,0x3F,0x05,0xFD,0xC8,0xFF,0x04,0x00,0x90,0x7A,0x45,0x05,0xFD,0xC8,0xFF,0x05,0x00,0x70,0x7B,0x45,0x05,0xFD,0xC8,0xFF,0x06,0x00,0x80,0x7B,0x45,0x05,0xFD,0xD9,0xFF,0x04,0x00,0x50,0x2A,0x47,0x05,0xFF,0x5A,0x00,0x00,0xFA,0x43,0x02,0xFD,0x3A,0xC8,0x00,0x02,0xFD,0x3A,0x0A,0x00,0x0F,0x00,0x00,0x00,0x00,0x00,0x8B,0x16};
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

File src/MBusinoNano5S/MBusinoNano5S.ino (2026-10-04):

/*
# MBusino Nano: M-Bus --> MQTT-Gateway via Ethernet (or Wifi)
Only M-Bus, no accessories.

Ethernet is prioritized over wifi. MQTT connection is possible with both. If a connection get lost, MBusino will try the other one during ongoing operation.
If no known wifi is found when starting, but ethernet is connected, wifi will be switched off completely. Even if there is no Ethernet connection, 
an AP with a captive portal is set up.


https://github.com/Zeppelin500/MBusino/

## Licence
****************************************************
This program is free software: you can redistribute it and/or modify it under the terms of the GNU General Public License as published by
the Free Software Foundation, either version 3 of the License, or (at your option) any later version. This program is distributed in the hope that it will be useful,
but WITHOUT ANY WARRANTY; without even the implied warranty of MERCHANTABILITY or FITNESS FOR A PARTICULAR PURPOSE.  See the GNU General Public License for more details.
You should have received a copy of the GNU General Public License along with this program.  If not, see <http://www.gnu.org/licenses/>.
****************************************************
*/

#include <SPI.h>
#include <ETH.h>
#include <Arduino.h>
#include <PubSubClient.h>
#include <Wire.h>
#include <ESPAsyncWebServer.h> 
#include <DNSServer.h>
#include <ArduinoOTA.h>
#include <WiFi.h>
#include <AsyncTCP.h>
#include <MBusinoLib.h>  // Library for decode M-Bus
#include <ArduinoJson.h>
#include <EEPROM.h>
#include <MBusCom.h>

#define MBUSINO_VERSION "1.1.2"

// EEPROM flag constants
#define EEPROM_CREDENTIALS_OLD 500
#define EEPROM_CREDENTIALS_NEW 501

#define MBUS_ADDRESS 254


// Pins for an ESP32 C3 Supermini standard SPI
#ifndef ETH_PHY_CS
#define ETH_PHY_TYPE     ETH_PHY_W5500
#define ETH_PHY_ADDR     0
#define ETH_PHY_CS       7
#define ETH_PHY_IRQ      2
#define ETH_PHY_RST      3
#define ETH_PHY_SPI_HOST SPI2_HOST
#define ETH_PHY_SPI_SCK  4
#define ETH_PHY_SPI_MISO 5
#define ETH_PHY_SPI_MOSI 6
#endif

static bool eth_connected = false;

NetworkClient ethClient;
HardwareSerial MbusSerial(1);
MBusinoLib payload(254);
WiFiClient wfClient;
PubSubClient client;
DNSServer dnsServer;
AsyncWebServer server(80);
MBusCom mbus(&MbusSerial,20,21);

struct settings {
  char ssid[65];
  char password[65];
  char mbusinoName[31];
  char broker[65];
  uint16_t mqttPort;
  uint16_t extension;
  char mqttUser[65];
  char mqttPswrd[65]; 
  uint32_t sensorInterval;
  uint32_t mbusInterval; 
  uint8_t mbusSlaves;
  uint8_t mbusAddress1;
  uint8_t mbusAddress2;
  uint8_t mbusAddress3;
  uint8_t mbusAddress4;
  uint8_t mbusAddress5;
  bool haAutodisc;
  bool telegramDebug;
} userData = {"SSID","Password","MBusino","192.168.1.8",1883,5,"mqttUser","mqttPassword",5000,120000,1,0xFE,0,0,0,0,true,false};

struct oldSettings {
  char ssid[30];
  char password[30];
  char mbusinoName[11];
  char broker[20];
  uint16_t mqttPort;
  uint16_t extension;
  char mqttUser[30];
  char mqttPswrd[30]; 
  uint32_t sensorInterval;
  uint32_t mbusInterval; 
  uint8_t mbusSlaves;
  uint8_t mbusAddress1;
  uint8_t mbusAddress2;
  uint8_t mbusAddress3;
  uint8_t mbusAddress4;
  uint8_t mbusAddress5;
  bool haAutodisc;
  bool telegramDebug;
} oldUserData = {"SSID","Password","MBusino","192.168.1.8",1883,5,"mqttUser","mqttPassword",5000,120000,1,0xFE,0,0,0,0,true,false};

uint8_t mbusAddress[5] = {0};

bool mqttcon = false;
bool apMode = false;
bool credentialsReceived = false;
uint16_t conCounter = 0;

uint8_t newAddress = 0;
bool newAddressReceived = false;
bool waitToSetAddress = false;

uint8_t currentAddress = 0;
uint8_t addressCounter = 0;
uint8_t currentAddressCounter = 0;
uint8_t pollingAddress = 0;

int Startadd = 0x13;  // Start address for decoding

uint8_t mbusLoopStatus = 0;
bool shc = true; //Switch Has Changed
uint8_t fields = 0;
bool fcb[5] = {0}; // M-Bus Frame Count Bit
bool initializeSlave[5] = {true}; // m-bus normalizing is needed
bool firstrun = true;
uint8_t recordCounter[5] = {0}; // count the received records for multible telegrams
char jsonstring[4096] = { 0 };
uint8_t address = 0; 
bool engelmann = false;
bool waitForRestart = false;
bool polling = false;
bool mtPolling = false;
bool wifiReconnect = false;
uint8_t usedMQTTconection = 0;
bool networkLost = false;
bool gotIP = false;

unsigned long timerMQTT = 15000;
unsigned long timerMbus = 0;
unsigned long timerInitialize = 0;
unsigned long timerSerialAvailable = 0;
unsigned long timerMbusDecoded = 0;
unsigned long timerMbusReq = 0;
unsigned long timerDebug = 0;
unsigned long timerReconnect = 0;
unsigned long timerWifiReconnect = 0;
unsigned long timerReboot = 0;
unsigned long timerSetAddress = 0;
unsigned long timerAutodiscover = 0;
unsigned long timerNetworkChange = 0;
unsigned long timerETHmessage = 0;
unsigned long timerLedAPmode = 0;

void setupServer();

uint8_t eeAddrCalibrated = 0;
uint8_t eeAddrCredentialsSaved = 32;
uint16_t credentialsSaved = 123;  // shows if EEPROM used befor for credentials

uint8_t adMbusMessageCounter = 0; // Counter for autodiscouver mbus message.

uint32_t minFreeHeap = 0;

//outsourced program parts
#include "networkEvents.h"
#include "html.h"
#include "mqtt.h"
#include "guiServer.h"
#include "autodiscover.h"

void heapCalc();
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

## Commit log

2023-09-27 Add files via upload
    Gehäuse
    [Mbusino v6.stl]
2023-09-30 Add files via upload
    verbessertes Gehäuse
    [Mbusino v11.stl]
2023-09-30 Delete Mbusino v6.stl
    durch V11 ersetzt
    [Mbusino v6.stl]
2023-10-02 Add files via upload
    Gehäuse final
    [Mbusino_case.stl]
2023-10-02 Delete Mbusino v11.stl
    durch aktuellere Version ersetzt
    [Mbusino v11.stl]
2023-10-05 Add files via upload
    Leiterplatte
    [MBusino_V03.fzz]
2023-10-10 in Ordner aufgeteilt
    [MBusino_V03.fzz, Mbusino_case.stl]
2023-10-10 PCB V04 hinzu
    [MBusino_V04.fzz]
2023-10-24 add MBusino_naked
    MBusino without sensors
2023-10-28 PCB V05 change pin assignment for DS18b20 JST XH
    [MBusino_V05.fzz]
2023-11-06 add sensostar dongle
    [sensostar_dongle.stl]
2023-11-07 power calculation Sensostar bugfix
    [MBusino.ino, MBusino_02.ino, MBusino_naked.ino]
2023-11-09 add MBusino calibrate
2023-12-05 Create Mbusino v05.stl
    [Mbusino v05.stl]
2023-12-24 wrong sensor assigment
2024-01-10 Add a hint - only one M-Bus device
2024-01-13 Create stecker v18.stl
    [stecker v18.stl]
2024-01-15 Fix not working intervals
    [MBusinoAP.ino]
2024-01-30 bugfix with first sensor offset if 7 sensors used
    [MBusinoAP.ino]
2024-02-04 fix device_class and state_class is empty
2024-02-06 fix address 0 issue
    [MBusinoAP.ino, MBusinoAP_2devices_new.ino, MBusino_naked_scan.ino]
2024-03-02 add mbus and sensor simulation
2024-04-15 0.9.4
    ## [0.9.4] - 2024-04-15
    ### Changed
    - separate decodeing and sending of records for a better stability
    - length of form text fields in html are now limited to the length of the variable
    [MBusino.ino, MBusino3S.ino]
2024-05-14 add a switch for Homeassitant autodiscovery messages
2024-11-09 add a link to the ESP32 S2 flash tutorial
2024-12-03 0.9.11
    ## [0.9.11] - 2024-12-03
    - increased time between M-Bus request and get response for slow slaves
    - placed sensor1.setWaitForConversion(false) etc. to the right place, to set the OneWire communication async
    - changed the BME280 topics to english language
    - toturial: ad links to the .bin files
    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
2025-01-28 0.9.15
    ## [0.9.15] - 2025-01-28
    - fixed problems with the webserver since 0.9.14
    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
    [MBusino.ino, MBusino3S.ino]
2025-01-30 ## [0.9.16] - 2025-01-30
    ## [0.9.16] - 2025-01-30
    - fixed again problems with the webserver since 0.9.14
    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
    [MBusino.ino, MBusino3S.ino]
2025-02-11 rename server.h to guiServer.h because of windows compile issues
    [MBusino.ino, MBusino3S.ino, MBusinoEth.ino]
2025-02-16 ## [0.9.18] - 2025-02-16
    ## [0.9.18] - 2025-02-16
    - rename outsourced code for the GUI-Server from server.h to guiServer.h because of Windows Compiling issues. (.bin files are not changed and sill 0.9.17)
    ### Added
    - case file for Z-Version
    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
    [MbusinoZ v7.stl, Mbusino_case.stl]
2025-02-27 0.9.19
    ## [0.9.19] - 2025-02-27
    - Sourced the M-Bus communication out to a Arduino IDE accessable Library --> MBusCom
    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
2025-03-28 0.9.20
    ## [0.9.20] - 2025-03-28
    - Improved WiFi stability for S2 mini (prevents crashes)
    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
    [MBusino.ino, MBusino3S.ino]
2025-07-21 0.9.22
    ## [0.9.22] - 2025-07-21
    - MBusinoLib 0.9.14
    - DS18B20 S6 with ESP32 S2 issue fixed
    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
    [MBusino.ino, MBusino5S.ino, MBusino5S_mt.ino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]
2025-07-23 bug fix with sensors
    [MBusino5S.ino]
2025-07-23 O.9.22b
    ## [0.9.22b] - 2025-07-21
    - little bugfix MBusino5S Sensors
    - all Files still 0.9.22
    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
2025-09-24 fix an issue with setting new m-bus addresses
    [MBusinoNano5S.ino]
2025-12-01 Update README with power supply information
    Added note about power supply compatibility with MBusino.
2025-12-29 add Case STL for Nano
    [MbusinoNano v13.stl]
2026-01-08 0.9.24
    ## [0.9.24] - 2026-01-08
    - HA audodicovery, change "object_id":"xxx" "default_entity_id":"sensor.xxx"
    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
2026-01-13 1.0.0
    ## [1.0.0] - 2026-01-13
    - Assigning all allowed M-Bus addresses (0-250) is now possible in the 5S firmware.
    - credentials storrages (SSID,Password, Broker, MQTT-Pasword and User) are now 64 characters long.
    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
    [MBusino.ino, MBusino5S.ino, MBusinoNano.ino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]
2026-05-18 fix: use MBUS_MAX_TELEGRAM_LEN for mbus_data buffer size
    The mbus_data buffer was sized to MBUS_DATA_SIZE which is too small
    for longer M-Bus telegrams. Change all 4 variants to use
    MBUS_MAX_TELEGRAM_LEN so MBusCom can handle extended telegrams.
    [MBusino.ino, MBusino5S.ino, MBusinoNano.ino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]
2026-07-10 fix: revert buffer to MBUS_DATA_SIZE for MBusCom v0.1.9 compat
    MBusCom v0.1.9 renamed MBUS_MAX_TELEGRAM_LEN back to MBUS_DATA_SIZE
    (value updated from 255 to 261). Revert sketches to use the original
    define name for backward compatibility.
    [MBusino.ino, MBusino5S.ino, MBusinoNano.ino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]
2026-07-10 bump version to 1.0.4, update CHANGELOG
    - Depends on MBusCom 0.1.9 (fixed get_response timeout)
    - Reverted buffer define to MBUS_DATA_SIZE for backward compat
    [MBusino.ino, MBusino5S.ino, MBusinoNano.ino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]
2026-07-10 Update binaries: v1.0.4 with MBusCom v0.1.9
    All6 variants compiled:
    - MBusino ESP32 S2 Mini + ESP8266 D1 Mini
    - MBusino5S ESP32 S2 Mini + ESP8266 D1 Mini
    - MBusinoNano C3 SuperMini
    - MBusinoNano5S C3 SuperMini
2026-07-15 feat: remove else 0 from value_template, add expire_after for M-Bus/OneWire/BME sensors
    - value_template: {{value_json if value_json is defined else 0}} → {{value_json}}
    Broken/empty payloads now keep previous state instead of reporting 0
    - expire_after added to M-Bus discovery payloads (3x mbusInterval in seconds)
    - expire_after added to OneWire/BME discovery payloads (3x sensorInterval in seconds)
    - bufferValue increased from 700 to 1024 (worst-case 715 bytes)
    Part of #57
2026-07-15 feat: HA availability, expire_after, value_template fix — all 4 variants (v1.1.0)
    - Port LWT/status topic fix to MBusino5S, MBusinoNano, MBusinoNano5S
    - Port availability_topic + expire_after to all discovery payloads
    - Remove else 0 from value_template in all variants
    - Increase autodiscover buffer to 1024 bytes
    - Bump version to 1.1.0
    - Update CHANGELOG with breaking change warning (LWT topic changed)
    - Update README version badge
    Fixes #57
    [MBusino.ino, MBusino5S.ino, MBusinoNano.ino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]
2026-09-19 fix: build-Ordner-Namen an Arduino IDE 2 Tutorials anpassen + 3S→5S umbenannt
    - Build-Ordner umbenannt: s2_mini→esp32.esp32.lolin_s2_mini, d1_mini→esp8266.esp8266.d1_mini, c3_supermini→esp32.esp32.makergo_c3_supermini
    - MBusino5S Tutorial: alle MBusino3S Referenzen → MBusino5S
    - Bild 3Sconfig.png → 5Sconfig.png
2026-10-04 v1.1.2: Scale expire_after with M-Bus slave rotation (fixes #65)
    - MBusino5S + MBusinoNano5S: expire_after = mbusInterval/1000 * 3 * max(1, mbusSlaves)
    - Before: fixed 3 x mbusInterval regardless of slave count. Each slave is
    only polled once per full rotation (mbusSlaves x mbusInterval), so with
    3+ slaves the HA sensors expired between two of their updates
    - Version 1.1.2 in all 4 variants, CHANGELOG + README badge updated,
    all binaries rebuilt (6/6 passed)
    [MBusino.ino, MBusino5S.ino, MBusinoNano.ino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]
2026-10-14 v1.2.0: HA device_class follows the M-Bus medium (water/gas)
    - All variants now pass the M-Bus header medium to
    MBusinoLib::getDeviceClass(code, medium): cumulative volume records get the
    matching Home Assistant device_class - water meters -> water, gas meters ->
    gas, anything else stays the generic volume. Fixes #67 (water meters no
    longer show up as generic volume).
    - Bump MBUSINO_VERSION to 1.2.0 (all 4 variants), README badge, CHANGELOG.
    - Depends on MBusinoLib 0.10.0 (broader HA device_class coverage +
    state_class total_increasing for consumption).
    - Rebuilt binaries for all variants.
2026-10-16 fix: W5500 auto-negotiation with fallback to forced 10M full duplex
    Forcing 10M full duplex unconditionally causes a duplex mismatch on
    switch ports with auto-negotiation (e.g. UniFi defaults): the port
    falls back to half duplex, DHCP fails and the 2 s ETH restart loop
    makes the port flap.
    Start with auto-negotiation and toggle to forced 10M full duplex (and
    back) when no IP is received within 15 s after link up. Store the
    working mode in EEPROM so equipment that needs forced mode (Fritzbox
    7590, PoE extenders) uses it right away on the next boot.
    Also start the DHCP timeout at the first link up after ETH.begin() so
    link flapping cannot postpone it forever, and let MQTT connect via
    Etherne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
2026-10-16 feat: M-Bus debug page in the web interface
    Add /mbus to MBusinoNano and MBusinoNano5S. The page shows the last 10
    polls (time, address, status, raw telegram in hex) and the last decoded
    telegram (header and records), refreshes every 2 s, shows the time until
    the next poll and has a "Poll now" button. The data is served as JSON
    at /mbus.json; a mutex guards the log because the web server runs in
    its own FreeRTOS task.
    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
2026-10-16 fix: Ethernet mode fallback without link, link mode setting in web GUI
    - Also switch the link mode if no link comes up at all within 20 s
    after ETH.begin(). Some W5500 boards get no link with the wrong
    mode, so the DHCP timeout alone never triggered the fallback.
    - Only switch modes until a mode got an IP since start; afterwards a
    missing IP only restarts the W5500 in the same mode.
    - Restart the DHCP timeout at the next link up after a working cable
    was unplugged.
    - Add "Ethernet link mode" to the setup page: automatic (default),
    auto negotiation or forced 10M full duplex, stored in EEPROM.
    Publish the active mode as <name>/settings/ethLinkMode.
    The W5500 driver in arduino-esp3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
2026-10-17 fix: no transport switch during an intentional ETH restart, timestamp [ETH]/[NET] logs
    Observed on a Fritzbox 7590 during the link mode fallback: while loop() restarts
    ETH for the mode change, eth_connected is false for a moment. That made
    - the MQTT client get re-pointed at the Wi-Fi client, and
    - the wifiReconnect path call WiFi.reconnect(), re-enabling the radio that was
    deliberately switched off for the single-transport rule,
    so MQTT failed with 'unable to connect server' until Ethernet came back.
    - add an ethRestarting marker: set when loop() restarts ETH for a link mode
    change, cleared once an IP is back or after the grace period; skip the
    transport switch and the Wi-Fi reconnec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
2026-10-17 test: [LOOP] first-iteration + heartbeat diagnostics, timestamp Wi-Fi reconnect lines
    Both the v1 and the v2 boot log show a ~20 s gap between the end of setup()
    ([BOOT] setup done at 9307 ms) and the first loop activity, which delays the
    MQTT connect by ~20 s (IP is already there at 3.3 s). Both logs show it, so it
    is systematic and pre-existing, not caused by the transport patch.
    Diagnostics:
    - [LOOP] first iteration at N ms (printed once)
    - [LOOP] alive at N ms every 5 s
    - millis() on the two 'Wi-Fi reconnect skipped' lines
    TEST DIAGNOSTICS - remove before merge.
2026-10-17 test: [LOOP] enter marker as the first statement of loop()
    v3 showed loop() first ran at 29310 ms while setup() finished at 9306 ms, but the
    v3 marker sat after ArduinoOTA.handle(), so it could not tell whether the loop
    task never ran or something inside the first iteration blocked. The core source
    shows ArduinoOTA.handle() is non-blocking in the idle path (FIONREAD + recvfrom
    with MSG_DONTWAIT, socket set O_NONBLOCK), so this marker at the very top of
    loop() decides it.
    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
2026-10-17 chore: remove the [LOOP] test diagnostics
    v4 result: [LOOP] enter at 29303 ms (the very first statement of loop()) while
    setup() finished at 9299 ms. So loop() itself was not called for 20 s - the loop
    task got no CPU between setup() returning and the first loop() pass, right after
    WiFi.mode(WIFI_OFF). Neither the sketch nor ArduinoOTA.handle() is involved (the
    handle() path is non-blocking: FIONREAD + recvfrom with MSG_DONTWAIT).
    This is pre-existing (v1 and v2 showed the same ~20 s, and the old firmware uses
    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
2026-10-17 fix: disable mDNS to avoid the lwIP/IGMP crash when the setup AP is shut down
    AP test on v4: while the setup AP runs and Ethernet gets an IP, the device died
    with a Guru Meditation (Load access fault). Symbolised against the matching ELF
    (sha256 13e0da6ba...):
    _mdns_service_task -> perform_event_action -> _mdns_enable_pcb
    -> _mdns_pcb_init -> _udp_join_group
    -> igmp_joingroup_netif -> igmp_lookup_group -> igmp_lookfor_group (lwIP)
    The mDNS component crashes while joining its multicast group when a netif appears
    or is torn down - here: Ethernet coming up while the setup AP / Wi-Fi is switched
    off (a path only reachable through the new single-transport shutdown). MBusino
    does not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
2026-10-17 Build the M-Bus debug page for ESP32 only (ESP8266 has no FreeRTOS semaphores)
2026-10-18 docs(LED): Nano variants keep the LED on when MQTT is connected
    README, CHANGELOG and the comments in the Nano sketches claimed that the
    LED is switched off once MQTT is connected. The code does the opposite:
    reconnect() in mqtt.h writes LOW after a successful connect, and the LED on
    the ESP32-C3 Nano is active-low (LOW = lit, confirmed on hardware), so a
    connected broker leaves the LED steadily on. Nothing writes the pin again
    after the connect (the Nano variants have no alive pulse).
    No functional change: only README, CHANGELOG and comments are corrected
    (the setup() digitalWrite(LED_BUILTIN, HIGH) stays, it just gained a
    comment that explains the polarity).
    Build check: MBusinoNano and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
2026-10-18 feat(update): progress bar, real error reason and a restart that no longer races the response
    The /update page was a plain form POST: the browser froze it until the whole
    file was written, then showed only "success, restart now" or "FAIL" as raw
    text, and after success the device restarted without any hint when to reload.
    - update_html (all four variants, byte-identical): submit via XMLHttpRequest
    with a live progress bar (upload.onprogress - honest, because the browser
    streams the file into the flash in the same rhythm), phase messages
    (uploading %, verifying, waiting for the device), then poll GET / until the
    device answers again before redirecting home. Bounded timeouts: upload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
2026-10-18 Release 1.3.2
    Bumps MBUSINO_VERSION to 1.3.2 in all four sketches and the README badge,
    moves the [Unreleased] entries (update page progress, update-response reboot
    race fix) into a new [1.3.2] - 2026-10-18 section, and adds the documentation
    fixes that landed after 1.3.1 (README LED state on the Nano variants from
    #75, tutorial link/partition-typo fixes from #74).
    Includes the update-progress feature branch (PR #76); the binaries are
    rebuilt in the following commit.
2026-10-22 Release 1.3.3: switch to OneWireNg (fixes DS18B20 on GPIO > 33)
    Replace Paul Stoffregen's OneWire 2.3.8 with OneWireNg 0.14.1 in the
    MBusino and MBusino5S variants. The old library silently blocks GPIO > 33
    in directModeOutput() (written for the classic ESP32 where GPIO 34-39
    are input-only); on the ESP32-S2 (lolin S2 mini) these pins are fully
    output-capable, so the DS18B20 sensors on S6 (GPIO 35) and S7 (GPIO 33)
    never worked - no error, no warning, the bus just stayed silent
    (PaulStoffregen/OneWire issue #122, same board, same symptom).
    OneWireNg supports the ESP32-S2 (tested upstream on an ESP32-S2-WROVER)
    and ships a drop-in OneWire.h compatibility wrapper, so the
    DallasTemperature-bas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
